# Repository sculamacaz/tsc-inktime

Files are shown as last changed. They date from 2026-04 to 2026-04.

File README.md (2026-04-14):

# InkTime

Author: Luca Mazilescu

## Block Diagram

<p align="center">
  InkTime Block Diagram
</p>

## Hardware Functionality

### Microcontroller

The system is built around a Nordic **nRF52840** SoC (Arm Cortex-M4F @ 64 MHz, 1 MB flash, 256 kB RAM). It was chosen because it integrates a 2.4 GHz radio supporting Bluetooth Low Energy alongside a USB 2.0 full-speed controller, which covers both the wireless sync path and the USB-C data path without any external transceiver. The MCU runs from a 32 MHz high-frequency crystal (XC1/XC2) for the radio and CPU, and a 32.768 kHz low-frequency crystal (XL1/XL2) for the RTC and low-power sleep timing — accurate timekeeping is the whole point of a watch, so the LFXO is not optional.

An on-board 2.4 GHz chip antenna (2450AT18B100E) is placed at the edge of the PCB with a keep-out area underneath, fed from the `ANT` pin through a matching network.

### Display — E-Paper (SPI)

A reflective e-paper display is driven over **SPI** using SCK (P0.02), MOSI (P0.03) and a dedicated chip-select (P0.05). Three auxiliary GPIOs handle the panel-specific control lines: `EPD_DC` (P0.15) switches between command and data bytes, `EPD_RST` (P0.16) resets the display controller, and `EPD_BUSY` (P0.17) is an input the MCU polls while the panel completes a refresh. The display connects through a 24-pin FPC.

Because e-paper draws current only during a refresh (and essentially zero while displaying a static image), the entire display rail is gated by a PFET whose gate is driven from P1.01. Firmware can therefore cut power to the panel completely between updates, which is the dominant reason this watch can be expected to last days on a charge rather than hours.

### IMU — BMA421 (I²C)

A Bosch **BMA421** 3-axis accelerometer sits on the shared I²C bus. It provides raw acceleration data plus on-chip step counting functionality. Two interrupt lines, `IMU_INT1` (P0.08) and `IMU_INT2` (P1.08), let the sensor wake the MCU from deep sleep when a gesture or step event occurs, so the CPU does not have to poll the bus continuously.

### Haptics — DRV2605 (I²C)

A TI **DRV2605L** haptic driver actuates a coin LRA/ERM motor for notifications and UI feedback. It is configured over I²C and can play back effects from its internal ROM library, so the MCU only issues short "play effect N" commands rather than streaming waveforms. An enable line (`HAPTIC_EN`, P0.12) lets the MCU fully power the driver down when idle.

### Power management — BQ25180 + MAX17048 + RT6160

USB-C provides 5 V in through a USBLC6-2SC6Y ESD protector, with the two required 5.1 kΩ CC pull-downs advertising the device as a sink. A **BQ25180** single-cell Li-ion charger manages the LiPo battery: it handles CC/CV charging from USB, switches between USB and battery as the system source, and reports faults over I²C and on the `PMIC_INT` line (P0.11).

The system rail is generated by an **RT6160** buck-boost regulator producing a stable `3V3` across the full battery voltage range (~3.0–4.2 V), which is important because a plain buck would drop out near end-of-discharge and a plain boost would waste efficiency when the cell is full.

State-of-charge is tracked by a **MAX17048** fuel gauge directly on the battery node. It uses Maxim's ModelGauge algorithm, so no external current-sense resistor is needed — the MCU just reads the remaining percentage and cell voltage over I²C, and an `ALERT` line (P1.10) fires on programmable under/over-voltage thresholds.

### Inputs — Buttons

Three user buttons are connected to P0.13, P0.14 and P1.02 as active-low inputs with RC debounce. They use the MCU's internal pull-ups and can trigger GPIOTE interrupts to wake the device from System OFF.

### Shared I²C bus

All four I²C peripherals (BMA421, MAX17048, DRV2605L, BQ25180) share a single bus on SDA (P0.06) and SCL (P0.07), with 3.3 kΩ pull-ups to `3V3`. The devices have distinct 7-bit addresses, so one TWI instance on the nRF52840 is sufficient. Running I²C at 400 kHz (Fast-mode) is more than enough headroom for the low-bandwidth status reads these sensors require.

### Debug

An SWD interface (`SWDCLK`, `SWDIO`, optional `SWO` on P1.00) is exposed through a Tag-Connect TC2030 footprint, which avoids placing a bulky 2×5 header on a wearable-sized PCB.

### Expected capabilities

With the hardware described above, firmware would be able to: keep accurate time from the LFXO-backed RTC, render watch faces and menus on the e-paper display, detect steps and wrist-raise via the BMA421, deliver haptic notifications, communicate with a phone over BLE, enumerate as a USB device for charging and data, and report battery percentage and charger state in real time.

## Pinout Table

| Pin | Signal | Direction | Peripheral | Description |
|-----|---|---|---|---|
| P0.02 | SPI_SCK | Output | E-Paper Display | SPI clock |
| P0.03 | SPI_MOSI | Output | E-Paper Display | SPI data out |
| P0.05 | EPD_CS | Output | E-Paper Display | Chip select |
| P0.06 | SDA | Bidir | Fuel Gauge, Charger, IMU, Haptics | Shared I2C data |
| P0.07 | SCL | Output | Fuel Gauge, Charger, IMU, Haptics | Shared I2C clock |
| P0.08 | IMU_INT1 | Input | IMU (BMA421) | Interrupt line 1 |
| P0.11 | PMIC_INT | Input | Charger (BQ25180) | Fault/status interrupt |
| P0.12 | HAPTIC_EN | Output | Haptics (DRV2605) | Driver enable |
| P0.13 | — | Input | Button 1 | User button |
| P0.14 | — | Input | Button 2 | User button |
| P0.15 | EPD_DC | Output | E-Paper Display | Data/command select |
| P0.16 | EPD_RST | Output | E-Paper Display | Display reset |
| P0.17 | EPD_BUSY | Input | E-Paper Display | Busy status |
| P0.18 | RESET | Input | — | System reset |
| P1.00 | SWO | Output | Debug (pad) | SWD trace output |
| P1.01 | — | Output | EPD power gate | EPD power control |
| P1.02 | — | Input | Button 3 | User button |
| P1.08 | IMU_INT2 | Input | IMU (BMA421) | Interrupt line 2 |
| P1.10 | ALERT | Input | Fuel Gauge (MAX17048) | UV/OV alert |
| D+ | D+ | Bidir | USB-C connector | USB data+ |
| D− | D- | Bidir | USB-C connector | USB data− |
| XL1/XL2 | — | — | 32.768 kHz crystal | Low-frequency clock |
| XC1/XC2 | — | — | 32 MHz crystal | High-frequency clock |
| SWDCLK | SWDCLK | Input | Debug (pad) | SWD clock |
| SWDIO | SWDIO | Bidir | Debug (pad) | SWD data |
| ANT | RF | Output | 2.4 GHz antenna | Wireless antenna feed |

## Bill of Materials

The full, JLCPCB validated table can be found in `Assets/JLCPCB_BOM.xlsx`. That version contains detailed information about each part, such as the associated schematic designators, descriptions, and more.

| Part Name |Qty|Link (Order + Datasheet)|
| :-- | :--: | :--: |
|BMA421|1|[Link](https://jlcpcb.com/partdetail/BoschSensortec-BMA421/C5242966)|
|0201X104K100NT|5|[Link](https://jlcpcb.com/partdetail/270391-0201X104K100NT/C284966)|
|CGA0402X5R475M250GT|1|[Link](https://jlcpcb.com/partdetail/HRE-CGA0402X5R475M250GT/C6119795)|
|KH-TYPE-C-16P|1|[Link](https://jlcpcb.com/partdetail/Shenzhen_KinghelmElec-KH_TYPE_C16P/C709357)|
|RT6160AWSC|1|[Link](https://jlcpcb.com/partdetail/RichtekTech-RT6160AWSC/C7065276)|
|SDFL1608S100KTF|1|[Link](https://jlcpcb.com/partdetail/Sunlord-SDFL1608S100KTF/C1035)|
|0201WMF220KTEE|1|[Link](https://jlcpcb.com/partdetail/479910-0201WMF220KTEE/C473517)|
|EVPAKE31A|3|[Link](https://jlcpcb.com/partdetail/PANASONIC-EVPAKE31A/C569760)|
|GRM033R61A104KE15D|5|[Link](https://jlcpcb.com/partdetail/MurataElectronics-GRM033R61A104KE15D/C76934)|
|5034802400|1|[Link](https://jlcpcb.com/partdetail/MOLEX-5034802400/C122434)|
|CM8V-T1A-32.768KHZ-9PF-20PPM-TB-QA|1|[Link](https://jlcpcb.com/partdetail/C5366546)|
|BQ25180YBGR|1|[Link](https://jlcpcb.com/partdetail/TexasInstruments-BQ25180YBGR/C3682423)|
|DRV2605YZFR|1|[Link](https://jlcpcb.com/partdetail/TexasInstruments-DRV2605YZFR/C81079)|
|2450AT18B100E|1|[Link](https://jlcpcb.com/partdetail/JohansonDielectrics-2450AT18B100E/C2917717)|
|SI1308EDL-T1-GE3|1|[Link](https://jlcpcb.com/partdetail/VishayIntertech-SI1308EDL_T1GE3/C469327)|
|GRM155R60J226ME11D|2|[Link](https://jlcpcb.com/partdetail/408393-GRM155R60J226ME11D/C415703)|
|GRM155R61H105KE05D|9|[Link](https://jlcpcb.com/partdetail/1609005-GRM155R61H105KE05D/C1518208)|
|SDCL1005C15NJTDF|1|[Link](https://jlcpcb.com/partdetail/Sunlord-SDCL1005C15NJTDF/C27143)|
|0201WMJ0000TEE|3|[Link](https://jlcpcb.com/partdetail/259867-0201WMJ0000TEE/C270337)|
|CC0201KRX5R7BB473|1|[Link](https://jlcpcb.com/partdetail/YAGEO-CC0201KRX5R7BB473/C505465)|
|CL05A475MP5NRNC|5|[Link](https://jlcpcb.com/partdetail/24469-CL05A475MP5NRNC/C23733)|
|CL05A105KA5NQNC|6|[Link](https://jlcpcb.com/partdetail/53938-CL05A105KA5NQNC/C52923)|
|SDCL1005C3N9STDF|1|[Link](https://jlcpcb.com/partdetail/Sunlord-SDCL1005C3N9STDF/C14033)|
|CR0201FH5101G|2|[Link](https://jlcpcb.com/partdetail/LIZElec-CR0201FH5101G/C100142)|
|GRM0335C1H1R0BA01D|2|[Link](https://jlcpcb.com/partdetail/MurataElectronics-GRM0335C1H1R0BA01D/C85893)|
|CL05A106MQ5NUNC|3|[Link](https://jlcpcb.com/partdetail/16204-CL05A106MQ5NUNC/C15525)|
|0201CG120J500NT|4|[Link](https://jlcpcb.com/partdetail/51400-0201CG120J500NT/C50391)|
|BQ25180YBGR|1|[Link](https://jlcpcb.com/partdetail/TexasInstruments-BQ25180YBGR/C3682423)|
|MAX17048G+T10|1|[Link](https://jlcpcb.com/partdetail/2777647-MAX17048GT10/C2682616)|
|NX2016SA-32MHZ-STD-CZS-5|1|[Link](https://jlcpcb.com/partdetail/NDK-NX2016SA_32MHZ_STD_CZS5/C843260)|
|0201WMJ0332TEE|2|[Link](https://jlcpcb.com/partdetail/259848-0201WMJ0332TEE/C270318)|
|MBR0530|3|[Link](https://jlcpcb.com/partdetail/78464-MBR0530/C77336)|
|FTC252012SR47MBCA|1|[Link](https://jlcpcb.com/partdetail/6763488-FTC252012SR47MBCA/C5832368)|
|DMG2305UX-7|1|[Link](https://jlcpcb.com/partdetail/DiodesIncorporated-DMG2305UX7/C150470)|
|USBLC6-2SC6Y|1|[Link](https://jlcpcb.com/partdetail/TECHPUBLIC-USBLC62SC6Y/C5310974)|
|UCR006YVPFLR470|1|[Link](https://jlcpcb.com/partdetail/ROHMSemicon-UCR006YVPFLR470/C2089071)|
|CPF0201D10KC1|6|[Link](https://jlcpcb.com/partdetail/TEConnectivity-CPF0201D10KC1/C4187156)|
|744043680|1|[Link](https://jlcpcb.com/partdetail/WurthElektronik-744043680/C2045671)|
|GRM0335C1H101JA01D|1|[Link](https://jlcpcb.com/partdetail/MurataElectronics-GRM0335C1H101JA01D/C76922)|
|NRF52840-QIAA-R7|1|[Link](https://jlcpcb.com/partdetail/NordicSemicon-NRF52840_QIAAR7/C1851953)|

## Renders

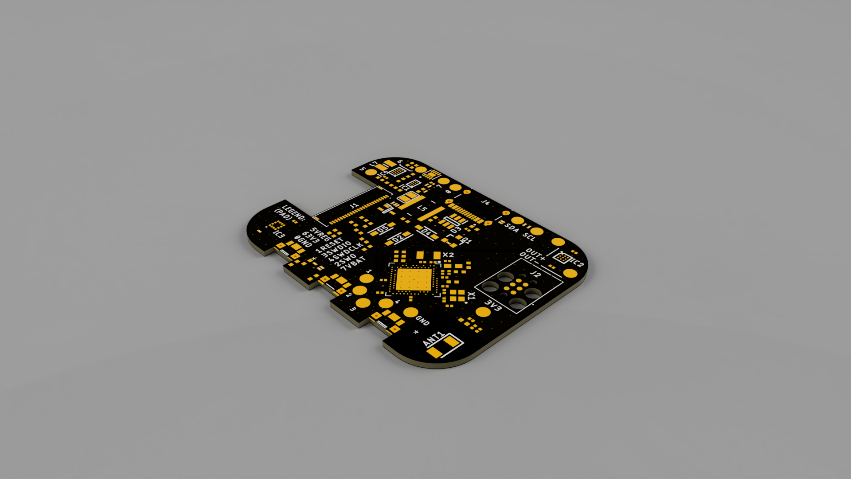
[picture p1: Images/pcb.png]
PCB

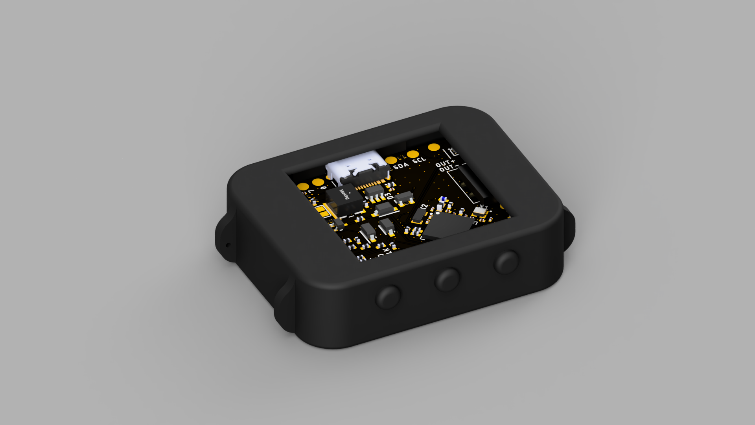
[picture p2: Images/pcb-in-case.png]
Case

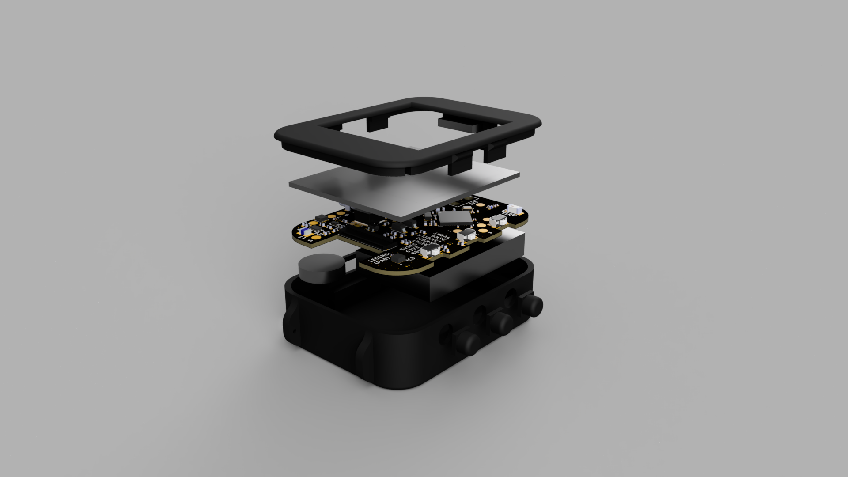
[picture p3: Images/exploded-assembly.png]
Exploded View


## Design Details

### Schematic and Components

The reference schematic was double-checked with information from each component's datasheet.
Mismatches were flagged and investigated, usually stemming from older versions of the reference circuits being used by the reference schematic.

### PCB Layout and Routing

Manufacturing parameters were kept within the ranges recommended by JLCPCB's standard rigid PCB assembly service.

A top ground pour was stitched to the ground plane, and more granular manual stitching was performed around the antenna feed line.

Teardrops were generated at most trace joints, and angles were carefully considered during routing.
Since Fusion exhibits buggy behavior when generating teardrops for off-grid rotations,
the shapes were manually smoothed for traces in close proximity to the MCU,
since it's placed at 45 degrees.

Due to space constraints and the minimum recommended text height being 1mm,
the silkscreen uses an indexed legend to allow labeling in narrow areas.
ICs, pads, and any larger components have labels on the silkscreen.

In order to achieve mechanical robustness, internal annular rings were kept large.
To accomodate, some unused pins of the MCU's package were masked, thus electrically isolating them from any traces running below.

VIA-in-pad (ViP) was liberally used for the smaller SMD multi-pin components.
DRC errors stemming from ViP-related clearance were manually approved.

Spatial constraints like the antenna's keep out zone, crystal oscillator trace length,
and IMU-shaker distance maximization were carefully considered. Decoupling capacitors were also placed in close proximity to the relevant pins.

USB (D+, D-) lines were differentially routed, keeping lengths approximately equal, and the lines close together.

### 3D Design

Detailed models of every component were retreived and integrated into the 3D PCB model.

The full closed-case assembly was checked for mechanical interference.
A potential problem was found regarding the maximum height of the battery listed in its datasheet,
as the case's bottom cavity doesn't provide enough clearance below the PCB.
This may or may not be a problem in practice, the case was left as-is to be tested in a prototype.

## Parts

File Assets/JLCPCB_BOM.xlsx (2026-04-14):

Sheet: JLCPCB BOM Tool - BOM Matching
JLCPCB BOM Tool - BOM Matching
BOM name：bom-JLCPCB Assembly Order.xlsx |  |  |  | Download Time：2026-04-15 00:02:17 |  |  |  | * Our matching results are updated in real-time, but stock and prices may change. If it's been over 24 hours, please re-match before placing your order.
PCB Assembled Qty：5 |  |  |  | Est. Total Price：143.8173 (Pre-order parts require a quotation for final pricing.)
Your BOM |  |  |  | Matched Parts |  |  |  |  |  |  | Order Information
Designator | Comment | Footprint | JLCPCB Part # | Matches | Part # | Manufacturer | Footprint | Description | Category | Warning | JLCPCB Part # | Product link | Source | Lib Type | MOQ | Availability | My Parts(JLCPCB Parts) | My Parts(Global sourcing & consigned parts) | Rec. Order Qty | Unit Price ($) | Total Price ($)
IC3 | BMA423 | LGA12 |  | Unconfirmed | BMA421 | Bosch Sensortec | LGA12 | LGA-12(2x2) Accelerometers ROHS | Accelerometers |  | C5242966 | https://jlcpcb.com/partdetail/BoschSensortec-BMA421/C5242966 | In-stock | Extended | 1 | 2037 | 0 | 0 | 5 | 0.841 | 4.205
C23,C27,C32,C34,C42 | 0.1uF | 0201 |  | Unconfirmed | 0201X104K100NT | FH (Guangdong Fenghua Advanced Tech) | 0201 | 100nF 10V X5R ±10% 0201 Multilayer Ceramic Capacitors MLCC - SMD/SMT ROHS | Multilayer Ceramic Capacitors MLCC - SMD/SMT | 1.The comment (0201X104K100NT) of this part does not match the one (0.1uF) provided in your BOM. Please confirm; | C284966 | https://jlcpcb.com/partdetail/270391-0201X104K100NT/C284966 | In-stock | Extended | 1 | 1767408 | 0 | 0 | 37 | 0.0008 | 0.0296
C2-EP-DR | 4.7uF/25V | 0402 |  | Unconfirmed | CGA0402X5R475M250GT | HRE | 0402 | 25V 4.7uF X5R ±20% 0402 Multilayer Ceramic Capacitors MLCC - SMD/SMT ROHS | Multilayer Ceramic Capacitors MLCC - SMD/SMT | 1.The comment (CGA0402X5R475M250GT) of this part does not match the one (4.7uF/25V) provided in your BOM. Please confirm; | C6119795 | https://jlcpcb.com/partdetail/HRE-CGA0402X5R475M250GT/C6119795 | In-stock | Extended | 1 | 515427 | 0 | 0 | 15 | 0.0132 | 0.198
J4 | KH-TYPE-C-16P | SMD |  | Select by System | KH-TYPE-C-16P | Shenzhen Kinghelm Elec | SMD | -40℃~+85℃ 1 10,000 cycles 16P 30V 3A 7.81mm Female Surface Mount, Right Angle Type-C SMD USB Connectors ROHS | USB Connectors |  | C709357 | https://jlcpcb.com/partdetail/Shenzhen_KinghelmElec-KH_TYPE_C16P/C709357 | In-stock | Extended | 1 | 250180 | 0 | 0 | 5 | 0.076 | 0.38
IC9 | RT6160AWSC | 15-UFBGA,WLCSP |  | Select by System | RT6160AWSC | Richtek Tech | 15-UFBGA,WLCSP | -40℃~+125℃ 1 1uA 2.025V~5.2V 2.2MHz 2.2V~5.5V 3A Adjustable Buck-Boost Buck-Boost Built-in Yes WLCSP-15B(2.3x1.4) DC-DC Converters ROHS | DC-DC Converters |  | C7065276 | https://jlcpcb.com/partdetail/RichtekTech-RT6160AWSC/C7065276 | In-stock | Extended | 1 | 5993 | 0 | 0 | 5 | 0.5868 | 2.934
L2 | 10uH | 0603 |  | Unconfirmed | SDFL1608S100KTF | Sunlord | 0603 | 1.85Ω 10uH 17MHz 30@2MHz 3mA ±10% 0603 Inductors (SMD) ROHS | Inductors (SMD) | 1.The comment (SDFL1608S100KTF) of this part does not match the one (10uH) provided in your BOM. Please confirm; | C1035 | https://jlcpcb.com/partdetail/Sunlord-SDFL1608S100KTF/C1035 | In-stock | Basic | 1 | 314612 | 0 | 0 | 20 | 0.0175 | 0.35
R_TYPE_SEL | 2.2Ω | 0201 |  | Select by System | 0201WMF220KTEE | UNI-ROYAL(Uniroyal Elec) | 0201 | -100ppm/℃~+350ppm/℃ -55℃~+155℃ 2.2Ω 25V 50mW Thick Film Resistor ±1% 0201 Chip Resistor - Surface Mount ROHS | Chip Resistor - Surface Mount |  | C473517 | https://jlcpcb.com/partdetail/479910-0201WMF220KTEE/C473517 | In-stock | Extended | 1 | 489132 | 0 | 0 | 20 | 0.0012 | 0.024
SW_DN,SW_ENT,SW_UP | EVPAKE31A | SMD,3.9x2.9mm |  | Unconfirmed | EVPAKE31A | PANASONIC | SMD,3.9x2.9mm | -40℃~+85℃ 1.6N 1.6mm 15V 2.9mm 20mA 3.9mm 500,000 Cycles IP67 J-Lead Rectangular Button SPST Surface Mount,Vertical White With Bracket SMD,3.9x2.9mm Tactile Switches ROHS | Tactile Switches | 1.There may be multiple types of parts, but one type of part has been matched. Please check.; | C569760 | https://jlcpcb.com/partdetail/PANASONIC-EVPAKE31A/C569760 | In-stock | Extended | 1 | 26113 | 0 | 0 | 17 | 0.1596 | 2.7132
C5,C7,C8,C12,C19 | 100nF | 0201 |  | Unconfirmed | GRM033R61A104KE15D | Murata Electronics | 0201 | 100nF 10V X5R ±10% 0201 Multilayer Ceramic Capacitors MLCC - SMD/SMT ROHS | Multilayer Ceramic Capacitors MLCC - SMD/SMT | 1.The comment (GRM033R61A104KE15D) of this part does not match the one (100nF) provided in your BOM. Please confirm; | C76934 | https://jlcpcb.com/partdetail/MurataElectronics-GRM033R61A104KE15D/C76934 | In-stock | Extended | 1 | 1241377 | 0 | 0 | 37 | 0.002 | 0.074
J1 | 5034802400 | SMD,P=0.5mm, right angle |  | Select by System | 5034802400 | MOLEX | SMD,P=0.5mm, right angle | -40℃~+105℃ 0.3mm 0.5mm 1mm 24P 500mA 50V Double-Sided Contacts, Top and Bottom Entry Gold Hinged Lid Phosphor bronze Surface Mount, Right Angle SMD,P=0.5mm,Surface Mount，Right Angle FFC, FPC (Flat Flexible) Connector Assemblies ROHS | FFC, FPC (Flat Flexible) Connector Assemblies |  | C122434 | https://jlcpcb.com/partdetail/MOLEX-5034802400/C122434 | In-stock | Extended | 1 | 21 | 0 | 0 | 5 | 0.849 | 4.245
X2 | 32.768kHz | SMD,3.2x1.5mm |  | Select by System | CM8V-T1A-32.768KHZ-9PF-20PPM-TB-QA | Micro Crystal | SMD,3.2x1.5mm | -40℃~+125℃ 32.768kHz 70kΩ 9pF ±20ppm SMD2012-2P Crystals ROHS | Crystals |  | C5366546 | https://jlcpcb.com/partdetail/C5366546 | In-stock | Extended | 1 | 2791 | 0 | 0 | 5 | 0.6203 | 3.1015
EPD_C5 | 0.1uF/50V | 0402 |  | Unconfirmed | BQ25180YBGR | Texas Instruments | 0402 | -40℃~+125℃ 1 1A 3.2uA 4.65V 5.5V Charging IC I2C Lithium Battery、LiFePO4 Battery Support 恒流充电、恒压充电、涓流充电、自动再充电、充电终止、可编程充电电流、过放保护、Overcurrent Protection、Short-Circuit Protection、过压保护 DSBGA-8(1.1x1.6) Battery Management ROHS | Battery Management | 1.The footprint (DSBGA-8(1.1x1.6)) of this part does not match the one (0402) provided in your BOM. Please confirm; 2.Multiple lines in the BOM have been matched to the same part. Please check if the matching is correct. ; | C3682423 | https://jlcpcb.com/partdetail/TexasInstruments-BQ25180YBGR/C3682423 | In-stock | Extended | 1 | 969 | 0 | 0 | 10 | 1.7954 | 17.954
IC2 | DRV2605YZFR | BGA9 |  | Select by System | DRV2605YZFR | Texas Instruments | BGA9 | -40℃~+85℃ 2.5V~5.5V I2C DSBGA-9 Brushed DC Motor Drivers ROHS | Brushed DC Motor Drivers |  | C81079 | https://jlcpcb.com/partdetail/TexasInstruments-DRV2605YZFR/C81079 | In-stock | Extended | 1 | 334 | 0 | 0 | 5 | 1.3286 | 6.643
ANT1 | 2450AT18B100E | 1206 |  | Select by System | 2450AT18B100E | Johanson Dielectrics | 1206 | -45℃~+125℃ 0.5dBi 1.3mm 1.6mm 100MHz 2.45GHz 2W 3.2mm 50Ω Patch Antenna 1206 Antennas ROHS | Antennas |  | C2917717 | https://jlcpcb.com/partdetail/JohansonDielectrics-2450AT18B100E/C2917717 | In-stock | Extended | 1 | 317 | 0 | 0 | 5 | 1.0408 | 5.204
Q3 | SI1308EDL-T1-GE3 | SOT-323 |  | Select by System | SI1308EDL-T1-GE3 | Vishay Intertech | SOT-323 | -55℃~+150℃ 1 N-channel 1.4nC@10V 1.5A 1.5V 105pF 11pF 132mΩ@10V 23pF 30V 400mW N-Channel SOT-323 MOSFETs ROHS | MOSFETs |  | C469327 | https://jlcpcb.com/partdetail/VishayIntertech-SI1308EDL_T1GE3/C469327 | In-stock | Extended | 1 | 16217 | 0 | 0 | 7 | 0.1853 | 1.2971
C25,C33 | 22uF | 0402 |  | Unconfirmed | GRM155R60J226ME11D | Murata Electronics | 0402 | 22uF 6.3V X5R ±20% 0402 Multilayer Ceramic Capacitors MLCC - SMD/SMT ROHS | Multilayer Ceramic Capacitors MLCC - SMD/SMT | 1.The comment (GRM155R60J226ME11D) of this part does not match the one (22uF) provided in your BOM. Please confirm; | C415703 | https://jlcpcb.com/partdetail/408393-GRM155R60J226ME11D/C415703 | In-stock | Extended | 1 | 282949 | 0 | 0 | 14 | 0.0435 | 0.609
EPD_C1,EPD_C2,EPD_C6,EPD_C7,EPD_C8,EPD_C9,EPD_C10,EPD_C11,EPD_C12 | 1uF/50V | 0402 |  | Select by System | GRM155R61H105KE05D | Murata Electronics | 0402 | 1uF 50V X5R ±10% 0402 Multilayer Ceramic Capacitors MLCC - SMD/SMT ROHS | Multilayer Ceramic Capacitors MLCC - SMD/SMT |  | C1518208 | https://jlcpcb.com/partdetail/1609005-GRM155R61H105KE05D/C1518208 | In-stock | Extended | 1 | 264318 | 0 | 0 | 49 | 0.0304 | 1.4896
L3 | 15nH | 0402 |  | Unconfirmed | SDCL1005C15NJTDF | Sunlord | 0402 | 15nH 2.3GHz 300mA 500mΩ 8@100MHz ±5% 0402 Inductors (SMD) ROHS | Inductors (SMD) | 1.The comment (SDCL1005C15NJTDF) of this part does not match the one (15nH) provided in your BOM. Please confirm; | C27143 | https://jlcpcb.com/partdetail/Sunlord-SDCL1005C15NJTDF/C27143 | In-stock | Extended | 1 | 481616 | 0 | 0 | 20 | 0.0053 | 0.106
R2,R3,R4 | 0Ω | 0201 |  | Select by System | 0201WMJ0000TEE | UNI-ROYAL(Uniroyal Elec) | 0201 | -55℃~+155℃ 0Ω 25V 50mW Thick Film Resistor ±5% 0201 Chip Resistor - Surface Mount ROHS | Chip Resistor - Surface Mount |  | C270337 | https://jlcpcb.com/partdetail/259867-0201WMJ0000TEE/C270337 | In-stock | Extended | 1 | 908769 | 0 | 0 | 25 | 0.0008 | 0.02
C16 | 47nF | 0201 |  | Unconfirmed | CC0201KRX5R7BB473 | YAGEO | 0201 | 16V 47nF X5R ±10% 0201 Multilayer Ceramic Capacitors MLCC - SMD/SMT ROHS | Multilayer Ceramic Capacitors MLCC - SMD/SMT | 1.The comment (CC0201KRX5R7BB473) of this part does not match the one (47nF) provided in your BOM. Please confirm; | C505465 | https://jlcpcb.com/partdetail/YAGEO-CC0201KRX5R7BB473/C505465 | In-stock | Extended | 1 | 59476 | 0 | 0 | 20 | 0.0031 | 0.062
C6,C14,C20,C21,C43 | 4.7uF | 0402 |  | Unconfirmed | CL05A475MP5NRNC | Samsung Electro-Mechanics | 0402 | 10V 4.7uF X5R ±20% 0402 Multilayer Ceramic Capacitors MLCC - SMD/SMT ROHS | Multilayer Ceramic Capacitors MLCC - SMD/SMT | 1.The comment (CL05A475MP5NRNC) of this part does not match the one (4.7uF) provided in your BOM. Please confirm; | C23733 | https://jlcpcb.com/partdetail/24469-CL05A475MP5NRNC/C23733 | In-stock | Basic | 1 | 3874505 | 0 | 0 | 35 | 0.0059 | 0.2065
C15,C29,C30,C31,C37,C38 | 1uF | 0402 |  | Unconfirmed | CL05A105KA5NQNC | Samsung Electro-Mechanics | 0402 | 1uF 25V X5R ±10% 0402 Multilayer Ceramic Capacitors MLCC - SMD/SMT ROHS | Multilayer Ceramic Capacitors MLCC - SMD/SMT | 1.The comment (CL05A105KA5NQNC) of this part does not match the one (1uF) provided in your BOM. Please confirm; | C52923 | https://jlcpcb.com/partdetail/53938-CL05A105KA5NQNC/C52923 | In-stock | Basic | 1 | 11272053 | 0 | 0 | 40 | 0.0041 | 0.164
L1 | 3.9nH | 0402 |  | Unconfirmed | SDCL1005C3N9STDF | Sunlord | 0402 | 200mΩ 3.9nH 300mA 4GHz 8@100MHz Multilayer inductor 0402 Inductors (SMD) ROHS | Inductors (SMD) | 1.The comment (SDCL1005C3N9STDF) of this part does not match the one (3.9nH) provided in your BOM. Please confirm; | C14033 | https://jlcpcb.com/partdetail/Sunlord-SDCL1005C3N9STDF/C14033 | In-stock | Extended | 1 | 151853 | 0 | 0 | 20 | 0.0053 | 0.106
R1_USB,R2_USB | 5.1kΩ | 0201 |  | Select by System | CR0201FH5101G | LIZ Elec | 0201 | -55℃~+125℃ 25V 5.1kΩ 50mW Thick Film Resistor ±1% ±250ppm/℃ 0201 Chip Resistor - Surface Mount ROHS | Chip Resistor - Surface Mount |  | C100142 | https://jlcpcb.com/partdetail/LIZElec-CR0201FH5101G/C100142 | In-stock | Extended | 1 | 7185 | 0 | 0 | 20 | 0.0011 | 0.022
C3,C4 | 1pF | 0201 |  | Unconfirmed | GRM0335C1H1R0BA01D | Murata Electronics | 0201 | 1pF 50V C0G 0201 Multilayer Ceramic Capacitors MLCC - SMD/SMT ROHS | Multilayer Ceramic Capacitors MLCC - SMD/SMT | 1.The comment (GRM0335C1H1R0BA01D) of this part does not match the one (1pF) provided in your BOM. Please confirm; | C85893 | https://jlcpcb.com/partdetail/MurataElectronics-GRM0335C1H1R0BA01D/C85893 | In-stock | Extended | 1 | 94915 | 0 | 0 | 20 | 0.0031 | 0.062
C1-EP-DR,C24,C39 | 10uF | 0402 |  | Unconfirmed | CL05A106MQ5NUNC | Samsung Electro-Mechanics | 0402 | 10uF 6.3V X5R ±20% 0402 Multilayer Ceramic Capacitors MLCC - SMD/SMT ROHS | Multilayer Ceramic Capacitors MLCC - SMD/SMT | 1.The comment (CL05A106MQ5NUNC) of this part does not match the one (10uF) provided in your BOM. Please confirm; 2.There may be multiple types of parts, but one type of part has been matched. Please check.; | C15525 | https://jlcpcb.com/partdetail/16204-CL05A106MQ5NUNC/C15525 | In-stock | Basic | 1 | 9525242 | 0 | 0 | 25 | 0.0065 | 0.1625
C1,C2,C17,C18 | 12pF | 0201 |  | Unconfirmed | 0201CG120J500NT | FH (Guangdong Fenghua Advanced Tech) | 0201 | 12pF 50V C0G ±5% 0201 Multilayer Ceramic Capacitors MLCC - SMD/SMT ROHS | Multilayer Ceramic Capacitors MLCC - SMD/SMT | 1.The comment (0201CG120J500NT) of this part does not match the one (12pF) provided in your BOM. Please confirm; | C50391 | https://jlcpcb.com/partdetail/51400-0201CG120J500NT/C50391 | In-stock | Extended | 1 | 96412 | 0 | 0 | 30 | 0.0008 | 0.024
IC1 | BQ25180YBGR | BGA8 |  | Unconfirmed | BQ25180YBGR | Texas Instruments | BGA8 | -40℃~+125℃ 1 1A 3.2uA 4.65V 5.5V Charging IC I2C Lithium Battery、LiFePO4 Battery Support 恒流充电、恒压充电、涓流充电、自动再充电、充电终止、可编程充电电流、过放保护、Overcurrent Protection、Short-Circuit Protection、过压保护 DSBGA-8(1.1x1.6) Battery Management ROHS | Battery Management | 1.Multiple lines in the BOM have been matched to the same part. Please check if the matching is correct. ; | C3682423 | https://jlcpcb.com/partdetail/TexasInstruments-BQ25180YBGR/C3682423 | In-stock | Extended | 1 | 969 | 0 | 0 | 10 | 1.7954 | 17.954
U3 | MAX17048G+T10 | DFN-8-EP |  | Select by System | MAX17048G+T10 | Analog Devices Inc./Maxim Integrated | DFN-8-EP | -40℃~+85℃ 1 2.5V~4.5V 3uA I2C Lithium Battery Not supported Not supported DFN-8-EP(2x2) Battery Management ROHS | Battery Management |  | C2682616 | https://jlcpcb.com/partdetail/2777647-MAX17048GT10/C2682616 | In-stock | Extended | 1 | 10503 | 0 | 0 | 5 | 2.235 | 11.175
X1 | 32MHz | 4-SMD,2x1.6mm |  | Select by System | NX2016SA-32MHZ-STD-CZS-5 | NDK | 4-SMD,2x1.6mm | Crystal Oscillator SMD2016-4P Crystals ROHS | Crystals |  | C843260 | https://jlcpcb.com/partdetail/NDK-NX2016SA_32MHZ_STD_CZS5/C843260 | In-stock | Extended | 1 | 2780 | 0 | 0 | 5 | 0.2782 | 1.391
R17,R18 | 3.3kΩ | 0201 |  | Select by System | 0201WMJ0332TEE | UNI-ROYAL(Uniroyal Elec) | 0201 | -55℃~+155℃ 25V 3.3kΩ 50mW Thick Film Resistor ±200ppm/℃ ±5% 0201 Chip Resistor - Surface Mount ROHS | Chip Resistor - Surface Mount |  | C270318 | https://jlcpcb.com/partdetail/259848-0201WMJ0332TEE/C270318 | In-stock | Extended | 1 | 12985 | 0 | 0 | 20 | 0.0007 | 0.014
D2,D4,D5 | MBR0530 | SOD-123 |  | Select by System | MBR0530 | Jiangsu Changjing Electronics Technology Co., Ltd. | SOD-123 | 1 Independent 30V 5.5A 500mA 550mV@500mA 80uA@30V SOD-123 Schottky Diodes ROHS | Schottky Diodes |  | C77336 | https://jlcpcb.com/partdetail/78464-MBR0530/C77336 | In-stock | Extended | 1 | 89551 | 0 | 0 | 19 | 0.0351 | 0.6669
L7 | 0.47uH/6.5A/13mΩ | SMD,2x2.5mm |  | Select by System | FTC252012SR47MBCA | cjiang (Changjiang Microelectronics Tech) | SMD,2x2.5mm | 13mΩ 470nH 6.5A 7.5A ±20% 1008 Power Inductors ROHS | Power Inductors |  | C5832368 | https://jlcpcb.com/partdetail/6763488-FTC252012SR47MBCA/C5832368 | In-stock | Extended | 1 | 155998 | 0 | 0 | 9 | 0.0408 | 0.3672
Q1 | 20V/4.2A/52mΩ/1.4W | SOT23-3 |  | Select by System | DMG2305UX-7 | Diodes Incorporated | SOT23-3 | -55℃~+150℃ 1 P-Channel 1.4W 10.2nC@4.5V 20V 52mΩ@4.5V、100mΩ@2.5V 5A 77pF 808pF 85pF 900mV P-Channel SOT-23 MOSFETs ROHS | MOSFETs |  | C150470 | https://jlcpcb.com/partdetail/DiodesIncorporated-DMG2305UX7/C150470 | In-stock | Extended | 1 | 40635 | 0 | 0 | 9 | 0.1366 | 1.2294
D3 | USBLC6-2SC6Y | SOT23-6 |  | Select by System | USBLC6-2SC6Y | TECH PUBLIC | SOT23-6 | -55℃~+125℃ 0.6pF、1pF 12V 150W@8/20us 5V 6.5V 80nA 9A@8/20us IEC 61000-4-2、IEC 61000-4-5、IEC 61000-4-4 SOT-23-6 ESD and Surge Protection (TVS/ESD) ROHS | ESD and Surge Protection (TVS/ESD) |  | C5310974 | https://jlcpcb.com/partdetail/TECHPUBLIC-USBLC62SC6Y/C5310974 | In-stock | Extended | 1 | 4299 | 0 | 0 | 7 | 0.1801 | 1.2607
R1_EP_DR | 0.47Ω | 0201 |  | Select by Customer | UCR006YVPFLR470 | ROHM Semicon | 0201 | 0ppm/℃~+300ppm/℃ 100mW 470mΩ SMD Shunt ±1% 0201 Current Sense Resistors / Shunt Resistors ROHS | Current Sense Resistors / Shunt Resistors | 1.The comment (UCR006YVPFLR470) of this part does not match the one (0.47Ω) provided in your BOM. Please confirm; | C2089071 | https://jlcpcb.com/partdetail/ROHMSemicon-UCR006YVPFLR470/C2089071 | Pre-order | Extended | 53 | 0 | 0 | 0 | 53 | 0.1696 | 8.9888
R2_EP_DR,R5,R7,R8,R9,R_PWR_EPD | 10kΩ | 0201 |  | Unconfirmed | CPF0201D10KC1 | TE Connectivity | 0201 | -55℃~+155℃ 10kΩ 30mW Thin Film Resistor ±0.5% ±50ppm/℃ 0201 Chip Resistor - Surface Mount ROHS | Chip Resistor - Surface Mount | 1.There may be multiple types of parts, but one type of part has been matched. Please check.; | C4187156 | https://jlcpcb.com/partdetail/TEConnectivity-CPF0201D10KC1/C4187156 | Pre-order | Extended | 54 | 25 | 0 | 0 | 54 | 0.1672 | 9.0288
L5 | 744043680 | SMD,4.8x4.8mm |  | Select by System | 744043680 | Wurth Elektronik | SMD,4.8x4.8mm | 400mA 400mΩ 68uH ±30% SMD,4.8x4.8mm Power Inductors ROHS | Power Inductors |  | C2045671 | https://jlcpcb.com/partdetail/WurthElektronik-744043680/C2045671 | Pre-order | Extended | 12 | 0 | 0 | 0 | 12 | 0.8042 | 9.6504
C11 | 100pF | 0201 |  | Unconfirmed | GRM0335C1H101JA01D | Murata Electronics | 0201 | 100pF 50V C0G ±5% 0201 Multilayer Ceramic Capacitors MLCC - SMD/SMT ROHS | Multilayer Ceramic Capacitors MLCC - SMD/SMT | 1.The comment (GRM0335C1H101JA01D) of this part does not match the one (100pF) provided in your BOM. Please confirm; | C76922 | https://jlcpcb.com/partdetail/MurataElectronics-GRM0335C1H101JA01D/C76922 | Pre-order | Extended | 7408 | 2605 | 0 | 0 | 7408 | 0.0012 | 8.8896
U1 | NRF52840-QIAA-R7 | 73-VFQFN |  | Select by System | NRF52840-QIAA-R7 | Nordic Semicon | 73-VFQFN | -95dBm 1.7V~5.5V 2.4GHz 2.4GHz~2.4835GHz 2Mbps 4.82mA 6.26mA 8dBm SPI、USB、UART、I2S、PDM、PWM ZigBee、Bluetooth transceiver AQFN-73-EP(7x7) RF Transceiver ICs ROHS | RF Transceiver ICs |  | C1851953 | https://jlcpcb.com/partdetail/NordicSemicon-NRF52840_QIAAR7/C1851953 | Pre-order | Extended | 3 | 14 | 0 | 0 | 5 | 4.1631 | 20.8155

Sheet: Sheet 1
Table 1
Part Name | Qty | Slop | Link (Order + Datasheet)
BMA421 | 1 | IC3 | https://jlcpcb.com/partdetail/BoschSensortec-BMA421/C5242966
0201X104K100NT | 5 | C23,C27,C32,C34,C42 | https://jlcpcb.com/partdetail/270391-0201X104K100NT/C284966
CGA0402X5R475M250GT | 1 | C2-EP-DR | https://jlcpcb.com/partdetail/HRE-CGA0402X5R475M250GT/C6119795
KH-TYPE-C-16P | 1 | J4 | https://jlcpcb.com/partdetail/Shenzhen_KinghelmElec-KH_TYPE_C16P/C709357
RT6160AWSC | 1 | IC9 | https://jlcpcb.com/partdetail/RichtekTech-RT6160AWSC/C7065276
SDFL1608S100KTF | 1 | L2 | https://jlcpcb.com/partdetail/Sunlord-SDFL1608S100KTF/C1035
0201WMF220KTEE | 1 | R_TYPE_SEL | https://jlcpcb.com/partdetail/479910-0201WMF220KTEE/C473517
EVPAKE31A | 3 | SW_DN,SW_ENT,SW_UP | https://jlcpcb.com/partdetail/PANASONIC-EVPAKE31A/C569760
GRM033R61A104KE15D | 5 | C5,C7,C8,C12,C19 | https://jlcpcb.com/partdetail/MurataElectronics-GRM033R61A104KE15D/C76934
5034802400 | 1 | J1 | https://jlcpcb.com/partdetail/MOLEX-5034802400/C122434
CM8V-T1A-32.768KHZ-9PF-20PPM-TB-QA | 1 | X2 | https://jlcpcb.com/partdetail/C5366546
BQ25180YBGR | 1 | EPD_C5 | https://jlcpcb.com/partdetail/TexasInstruments-BQ25180YBGR/C3682423
DRV2605YZFR | 1 | IC2 | https://jlcpcb.com/partdetail/TexasInstruments-DRV2605YZFR/C81079
2450AT18B100E | 1 | ANT1 | https://jlcpcb.com/partdetail/JohansonDielectrics-2450AT18B100E/C2917717
SI1308EDL-T1-GE3 | 1 | Q3 | https://jlcpcb.com/partdetail/VishayIntertech-SI1308EDL_T1GE3/C469327
GRM155R60J226ME11D | 2 | C25,C33 | https://jlcpcb.com/partdetail/408393-GRM155R60J226ME11D/C415703
GRM155R61H105KE05D | 9 | EPD_C1,EPD_C2,EPD_C6,EPD_C7,EPD_C8,EPD_C9,EPD_C10,EPD_C11,EPD_C12 | https://jlcpcb.com/partdetail/1609005-GRM155R61H105KE05D/C1518208
SDCL1005C15NJTDF | 1 | L3 | https://jlcpcb.com/partdetail/Sunlord-SDCL1005C15NJTDF/C27143
0201WMJ0000TEE | 3 | R2,R3,R4 | https://jlcpcb.com/partdetail/259867-0201WMJ0000TEE/C270337
CC0201KRX5R7BB473 | 1 | C16 | https://jlcpcb.com/partdetail/YAGEO-CC0201KRX5R7BB473/C505465
CL05A475MP5NRNC | 5 | C6,C14,C20,C21,C43 | https://jlcpcb.com/partdetail/24469-CL05A475MP5NRNC/C23733
CL05A105KA5NQNC | 6 | C15,C29,C30,C31,C37,C38 | https://jlcpcb.com/partdetail/53938-CL05A105KA5NQNC/C52923
SDCL1005C3N9STDF | 1 | L1 | https://jlcpcb.com/partdetail/Sunlord-SDCL1005C3N9STDF/C14033
CR0201FH5101G | 2 | R1_USB,R2_USB | https://jlcpcb.com/partdetail/LIZElec-CR0201FH5101G/C100142
GRM0335C1H1R0BA01D | 2 | C3,C4 | https://jlcpcb.com/partdetail/MurataElectronics-GRM0335C1H1R0BA01D/C85893
CL05A106MQ5NUNC | 3 | C1-EP-DR,C24,C39 | https://jlcpcb.com/partdetail/16204-CL05A106MQ5NUNC/C15525
0201CG120J500NT | 4 | C1,C2,C17,C18 | https://jlcpcb.com/partdetail/51400-0201CG120J500NT/C50391
BQ25180YBGR | 1 | IC1 | https://jlcpcb.com/partdetail/TexasInstruments-BQ25180YBGR/C3682423
MAX17048G+T10 | 1 | U3 | https://jlcpcb.com/partdetail/2777647-MAX17048GT10/C2682616
NX2016SA-32MHZ-STD-CZS-5 | 1 | X1 | https://jlcpcb.com/partdetail/NDK-NX2016SA_32MHZ_STD_CZS5/C843260
0201WMJ0332TEE | 2 | R17,R18 | https://jlcpcb.com/partdetail/259848-0201WMJ0332TEE/C270318
MBR0530 | 3 | D2,D4,D5 | https://jlcpcb.com/partdetail/78464-MBR0530/C77336
FTC252012SR47MBCA | 1 | L7 | https://jlcpcb.com/partdetail/6763488-FTC252012SR47MBCA/C5832368
DMG2305UX-7 | 1 | Q1 | https://jlcpcb.com/partdetail/DiodesIncorporated-DMG2305UX7/C150470
USBLC6-2SC6Y | 1 | D3 | https://jlcpcb.com/partdetail/TECHPUBLIC-USBLC62SC6Y/C5310974
UCR006YVPFLR470 | 1 | R1_EP_DR | https://jlcpcb.com/partdetail/ROHMSemicon-UCR006YVPFLR470/C2089071
CPF0201D10KC1 | 6 | R2_EP_DR,R5,R7,R8,R9,R_PWR_EPD | https://jlcpcb.com/partdetail/TEConnectivity-CPF0201D10KC1/C4187156
744043680 | 1 | L5 | https://jlcpcb.com/partdetail/WurthElektronik-744043680/C2045671
GRM0335C1H101JA01D | 1 | C11 | https://jlcpcb.com/partdetail/MurataElectronics-GRM0335C1H101JA01D/C76922
NRF52840-QIAA-R7 | 1 | U1 | https://jlcpcb.com/partdetail/NordicSemicon-NRF52840_QIAAR7/C1851953

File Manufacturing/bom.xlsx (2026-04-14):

Comment | Designator | Footprint | JLCPCB Part #
0Ω | R2, R3, R4 | 0201 | C270337
0.1uF | C23, C27, C32, C34, C42 | 0201
0.1uF/50V | EPD_C5 | 0402 | C3682423
470mΩ | R1_EP_DR | 0201 | C2089071
0.47uH/6.5A/13mΩ | L7 | SMD,2x2.5mm | C5832368
100nF | C5, C7, C8, C12, C19 | 0201
100pF | C11 | 0201
10kΩ | R2_EP_DR, R5, R7, R8, R9, R_PWR_EPD | 0201 | C4187156
10uF | C1-EP-DR, C24, C39 | 0402
10uH | L2 | 0603
12pF | C1, C2, C17, C18 | 0201
15nH | L3 | 0402
1pF | C3, C4 | 0201
1uF | C15, C29, C30, C31, C37, C38 | 0402
1uF/50V | EPD_C1, EPD_C2, EPD_C6, EPD_C7, EPD_C8, EPD_C9, EPD_C10, EPD_C11, EPD_C12 | 0402 | C1518208
2.2Ω | R_TYPE_SEL | 0201 | C473517
20V/4.2A/52mΩ/1.4W | Q1 | SOT23-3 | C150470
22uF | C25, C33 | 0402
3.9nH | L1 | 0402
32.768kHz | X2 | SMD,3.2x1.5mm
32MHz | X1 | 4-SMD,2x1.6mm
3.3kΩ | R17, R18 | 0201 | C270318
4.7uF | C6, C14, C20, C21, C43 | 0402
4.7uF/25V | C2-EP-DR | 0402
47nF | C16 | 0201
5.1kΩ | R1_USB, R2_USB | 0201 | C100142
744043680 | L5 | SMD,4.8x4.8mm
EVPAKE31A | SW_DN, SW_ENT, SW_UP | SMD,3.9x2.9mm
2450AT18B100E | ANT1 | 1206
5034802400 | J1 | SMD,P=0.5mm, right angle
BMA421 | IC3 | LGA12
BQ25180YBGR | IC1 | BGA8
DRV2605YZFR | IC2 | BGA9
KH-TYPE-C-16P | J4 | SMD
MAX17048G+T10 | U3 | DFN-8-EP
MBR0530 | D2, D4, D5 | SOD-123
NRF52840-QIAA-R7 | U1 | 73-VFQFN
RT6160AWSC | IC9 | 15-UFBGA,WLCSP
SI1308EDL-T1-GE3 | Q3 | SOT-323
USBLC6-2SC6Y | D3 | SOT23-6

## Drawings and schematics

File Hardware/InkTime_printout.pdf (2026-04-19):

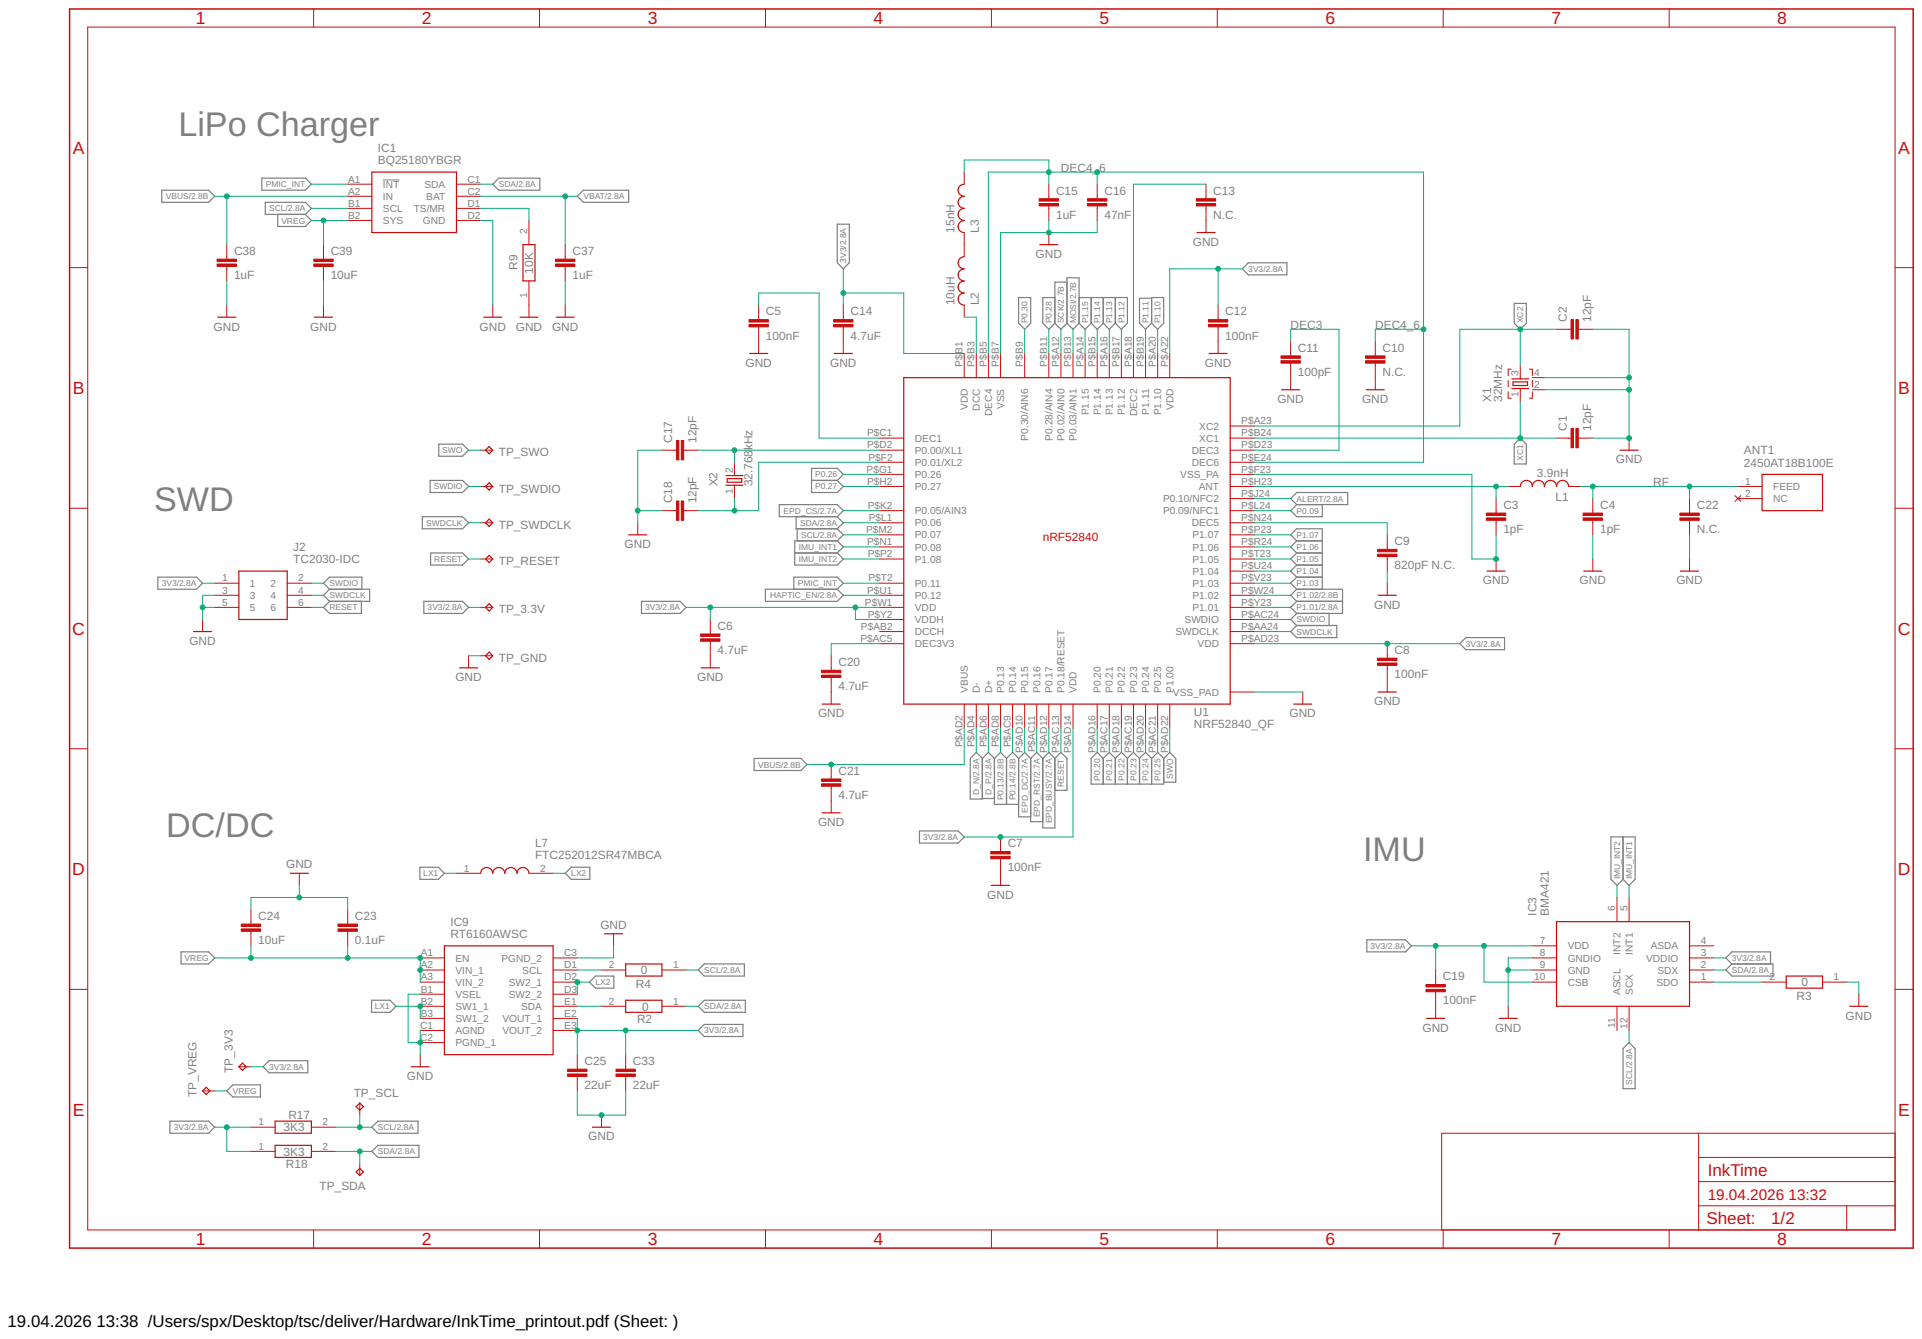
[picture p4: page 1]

19.04.2026 13:38 /Users/spx/Desktop/tsc/deliver/Hardware/InkTime_printout.pdf (Sheet: )

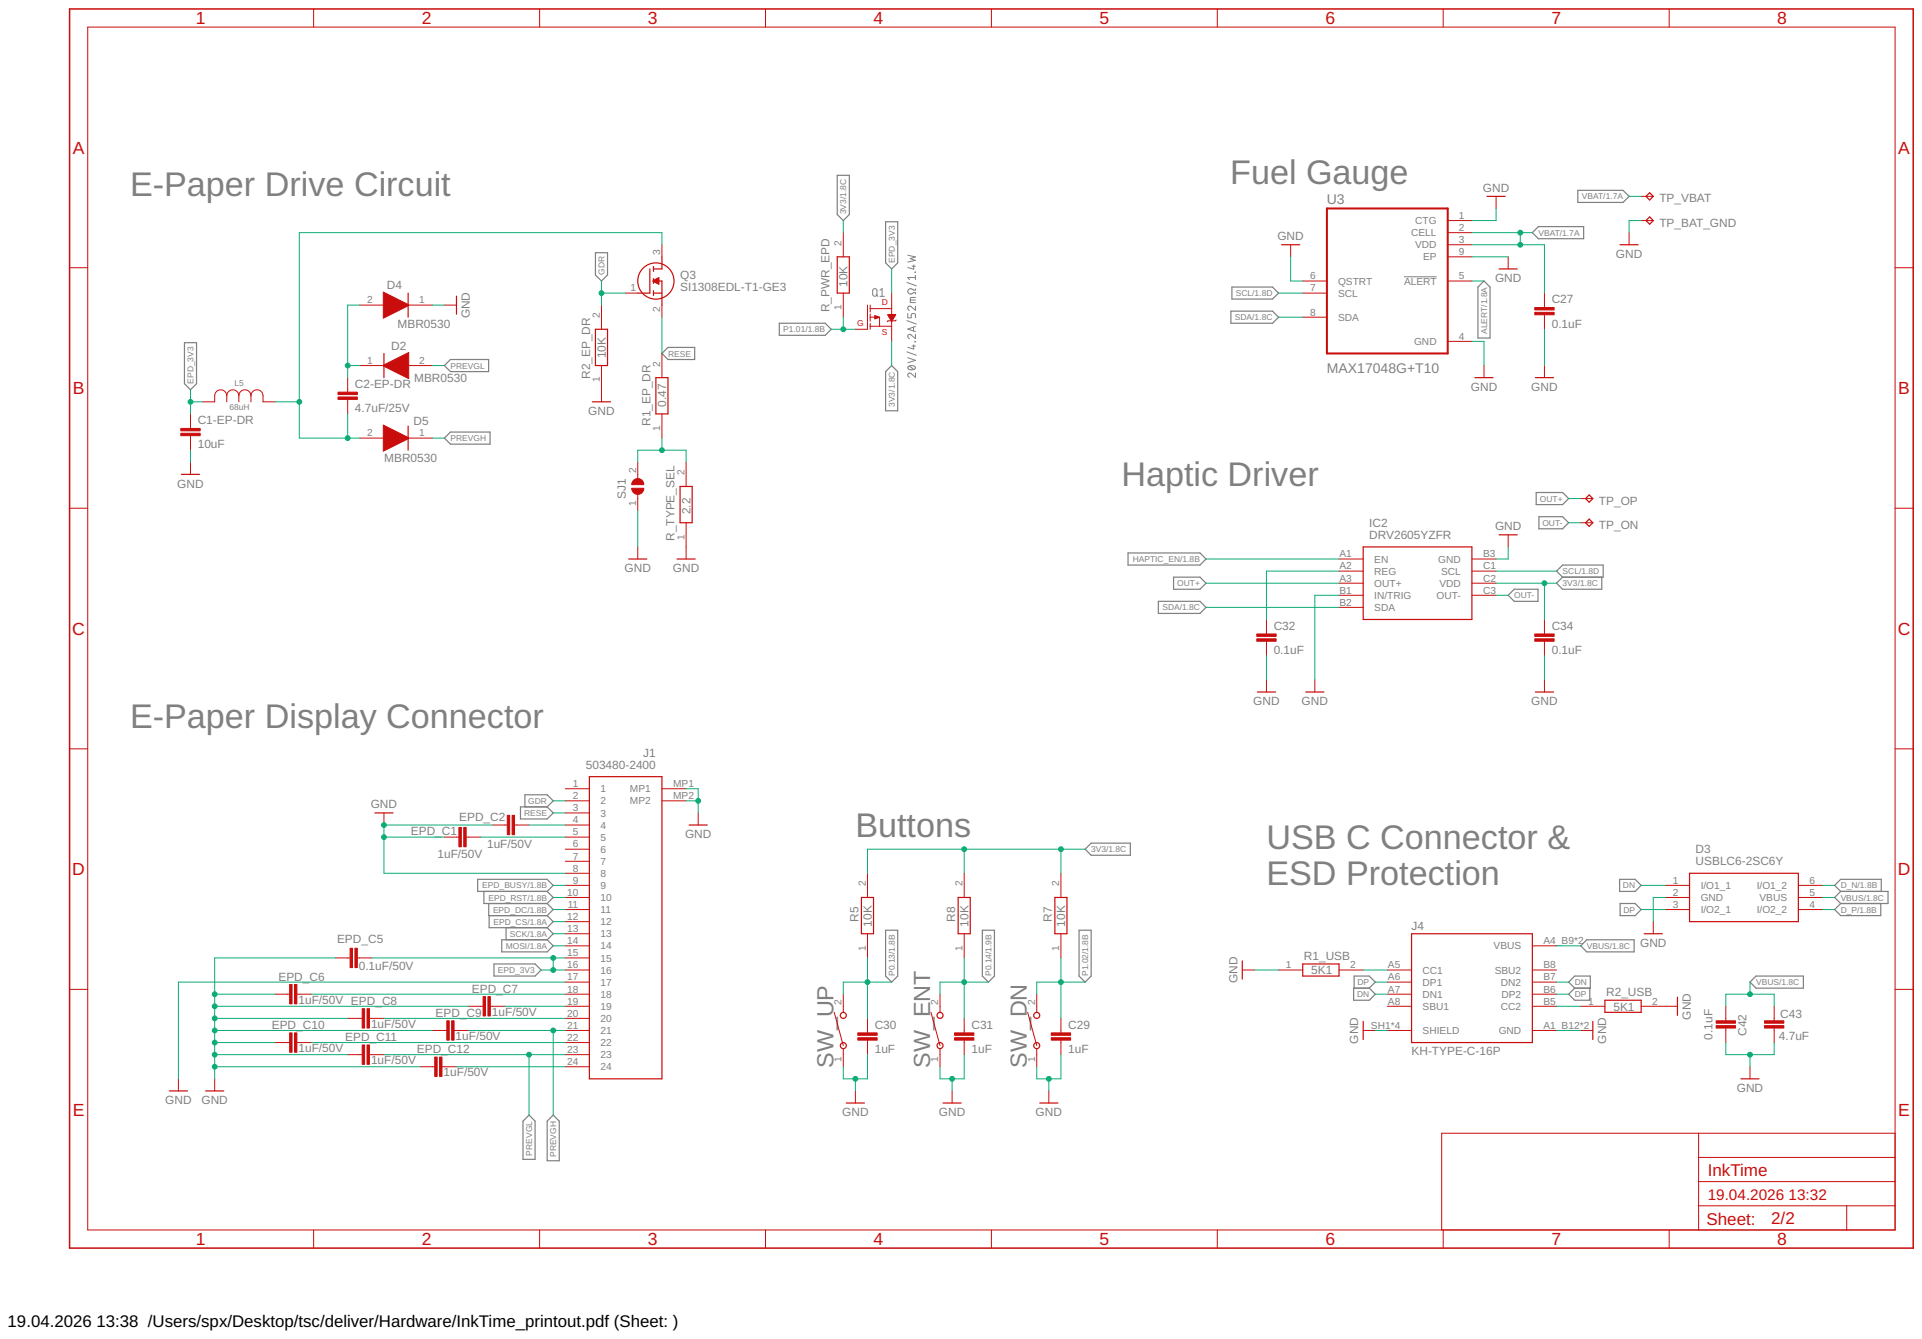
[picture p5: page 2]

EPD_C7 18
EPD_C9 | 1uF/50V 20

1uF/50V EPD_C8 | 19
EPD_C10 | 1uF/50V | 21
1uF/50V | EPD_C12 | 23

EPD_C11 | 1uF/50V | 22
1uF/50V | | | 24

19.04.2026 13:38 /Users/spx/Desktop/tsc/deliver/Hardware/InkTime_printout.pdf (Sheet: )

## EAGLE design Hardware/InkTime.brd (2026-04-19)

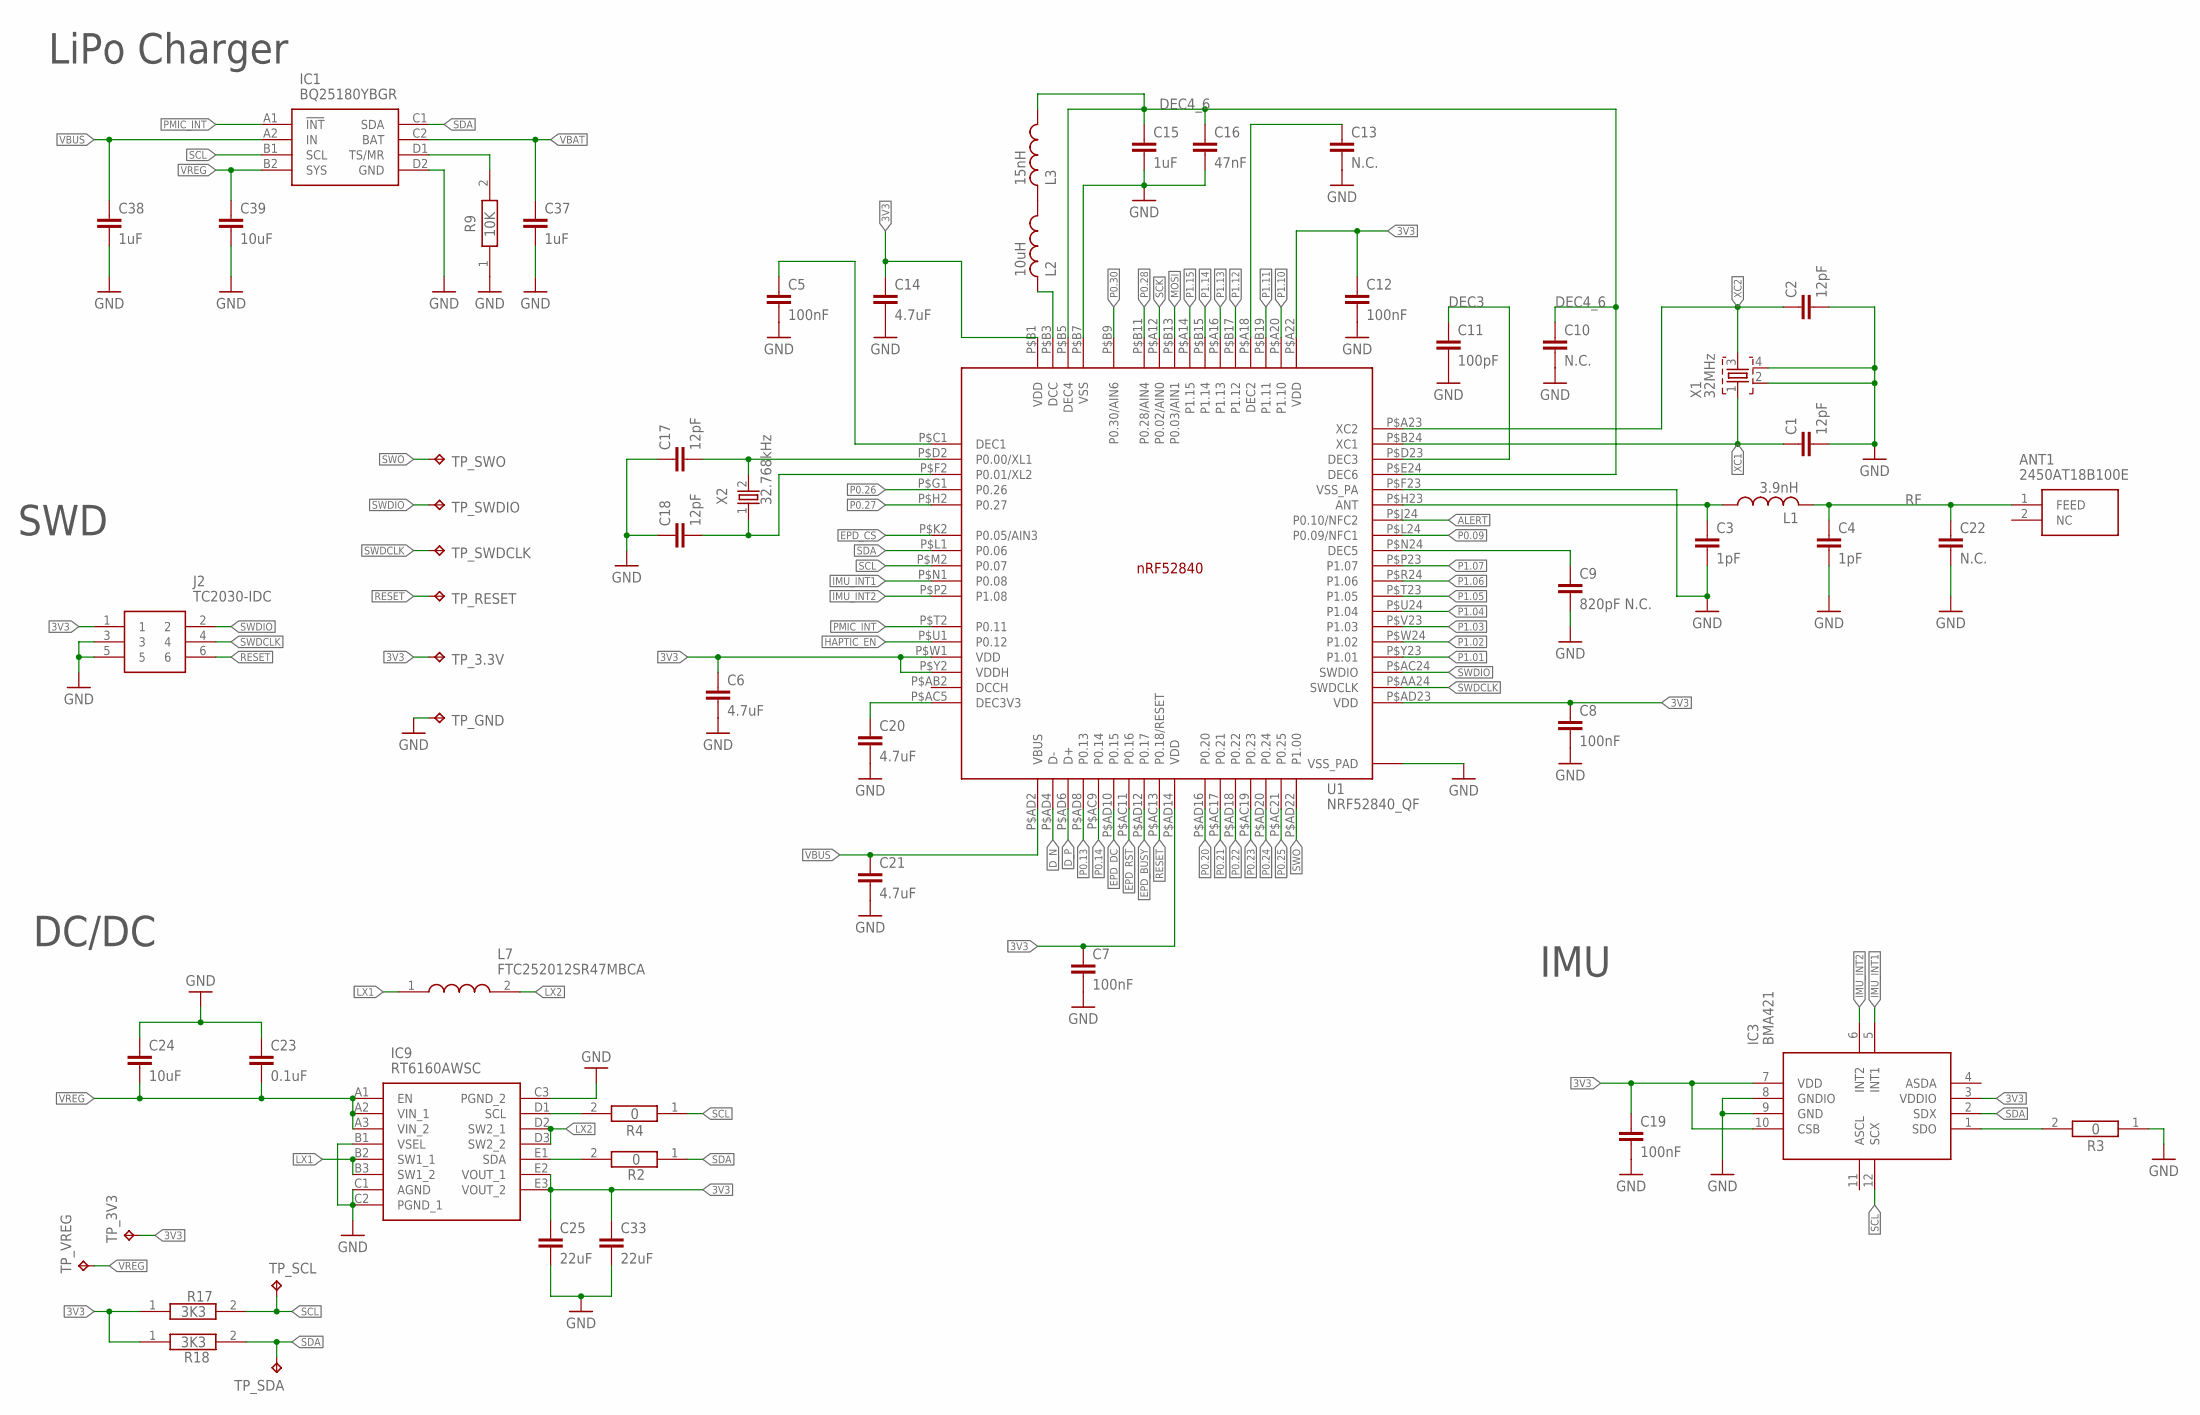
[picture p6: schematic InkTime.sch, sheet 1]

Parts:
ANT1: 2450AT18B100E; 2450AT18B100E_ANTC3216X140N
C1, C2, C17, C18: 12pF; NORDIC_NRF_3_RESC0201_N
C3, C4: 1pF; NORDIC_NRF_3_RESC0201_N
C5, C7, C8, C12, C19: 100nF; NORDIC_NRF_3_RESC0201_N
C6, C14, C20, C21: 4.7uF; NORDIC_NRF_3_RESC0402_N
C9: 820pF N.C.; NORDIC_NRF_3_RESC0201_N
C10, C13, C22: N.C.; NORDIC_NRF_3_RESC0201_N
C11: 100pF; NORDIC_NRF_3_RESC0201_N
C15, C37, C38: 1uF; NORDIC_NRF_3_RESC0402_N
C16: 47nF; NORDIC_NRF_3_RESC0201_N
C23: 0.1uF; NORDIC_NRF_3_RESC0201_N
C24, C39: 10uF; NORDIC_NRF_3_RESC0402_N
C25, C33: 22uF; NORDIC_NRF_3_RESC0402_N
IC1: BQ25180YBGR; BQ25180YBGR_BGA8C40P2X4_100X155X50
IC3: BMA421; BMA423_BMA423
IC9: RT6160AWSC; RT6160AWSC_BGA15C40P3X5_140X230X60
J2: TC2030-IDC; TC2030-IDC_TC2030IDC
L1: 3.9nH; NORDIC_NRF_2_RESC0402_N
L2: 10uH; NORDIC_NRF_2_RESC0603_N
L3: 15nH; NORDIC_NRF_2_RESC0402_N
L7: FTC252012SR47MBCA; MLP2016SR47MT0S1_INDC2016X100N
R2, R3, R4: 0; CPF0201D7K68C1_0201
R9: 10K; CPF0201D7K68C1_0201
R17, R18: 3K3; CPF0201D7K68C1_0201
TP_3.3V, TP_3V3: HECTOR_WATCH_1_TPTP20R; HECTOR_WATCH_1_TP20R
TP_GND: HECTOR_WATCH_1_TPTP20R; HECTOR_WATCH_1_TP20R
TP_RESET: HECTOR_WATCH_1_TPTP20R; HECTOR_WATCH_1_TP20R
TP_SCL: HECTOR_WATCH_1_TPTP20R; HECTOR_WATCH_1_TP20R
TP_SDA: HECTOR_WATCH_1_TPTP20R; HECTOR_WATCH_1_TP20R
TP_SWDCLK: HECTOR_WATCH_1_TPTP20R; HECTOR_WATCH_1_TP20R
TP_SWDIO: HECTOR_WATCH_1_TPTP20R; HECTOR_WATCH_1_TP20R
TP_SWO: HECTOR_WATCH_1_TPTP20R; HECTOR_WATCH_1_TP20R
TP_VREG: HECTOR_WATCH_1_TPTP20R; HECTOR_WATCH_1_TP20R
U1: NRF52840_QF; NORDIC_NRF_4_AQFN50P700X700X85_HS-74N_PINCLEAN2
X1: 32MHz; NORDIC_NRF_BT-XTAL_2016_N
X2: 32.768kHz; NORDIC_NRF_1_XTAL_3215_N

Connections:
3V3: C6.1, C7.1, C8.1, C12.1, C14.1, C19.1, C25.1, C33.1, IC3.3 (VDDIO), IC3.7 (VDD), IC3.10 (CSB), IC9.E2 (VOUT_1), IC9.E3 (VOUT_2), J2.1, R17.1, R18.1, TP_3.3V.TP, TP_3V3.TP, U1.P$A22 (VDD), U1.P$AD14 (VDD), U1.P$AD23 (VDD), U1.P$B1 (VDD), U1.P$W1 (VDD), U1.P$Y2 (VDDH); also elsewhere on the board
ALERT: U1.P$J24 (P0.10/NFC2); also elsewhere on the board
DEC3: C11.1, U1.P$D23 (DEC3)
DEC4_6: C10.1, C15.1, C16.1, L3.1, U1.P$B5 (DEC4), U1.P$E24 (DEC6)
D_N: U1.P$AD4 (D-); also elsewhere on the board
D_P: U1.P$AD6 (D+); also elsewhere on the board
EPD_BUSY: U1.P$AD12 (P0.17); also elsewhere on the board
EPD_CS: U1.P$K2 (P0.05/AIN3); also elsewhere on the board
EPD_DC: U1.P$AD10 (P0.15); also elsewhere on the board
EPD_RST: U1.P$AC11 (P0.16); also elsewhere on the board
GND: C1.2, C2.2, C3.2, C4.2, C5.2, C6.2, C7.2, C8.2, C9.2, C10.2, C11.2, C12.2, C13.2, C14.2, C15.2, C16.2, C17.1, C18.1, C19.2, C20.2, C21.2, C22.2, C23.1, C24.1, C25.2, C33.2, C37.2, C38.2, C39.2, IC1.D2 (GND), IC3.8 (GNDIO), IC3.9 (GND), IC9.B1 (VSEL), IC9.C1 (AGND), IC9.C2 (PGND_1), IC9.C3 (PGND_2), J2.3, J2.5, R3.1, R9.1, TP_GND.TP, U1.P$74 (VSS_PAD), U1.P$75 (VSS_PAD), U1.P$76 (VSS_PAD), U1.P$77 (VSS_PAD), U1.P$78 (VSS_PAD), U1.P$79 (VSS_PAD), U1.P$80 (VSS_PAD), U1.P$81 (VSS_PAD), U1.P$82 (VSS_PAD), U1.P$83 (VSS_PAD), U1.P$84 (VSS_PAD), U1.P$85 (VSS_PAD), U1.P$86 (VSS_PAD), U1.P$87 (VSS_PAD), U1.P$88 (VSS_PAD), U1.P$89 (VSS_PAD), U1.P$90 (VSS_PAD), U1.P$B7 (VSS), U1.P$F23 (VSS_PA), X1.2, X1.4; also elsewhere on the board
HAPTIC_EN: U1.P$U1 (P0.12); also elsewhere on the board
IMU_INT1: IC3.5 (INT1), U1.P$N1 (P0.08)
IMU_INT2: IC3.6 (INT2), U1.P$P2 (P1.08)
LX1: IC9.B2 (SW1_1), IC9.B3 (SW1_2), L7.1
LX2: IC9.D2 (SW2_1), IC9.D3 (SW2_2), L7.2
MOSI: U1.P$B13 (P0.03/AIN1); also elsewhere on the board
unnamed: L2.1, L3.2
unnamed: L2.2, U1.P$B3 (DCC)
unnamed: IC1.D1 (TS/MR), R9.2
unnamed: C3.1, L1.1, U1.P$H23 (ANT)
unnamed: C9.1, U1.P$N24 (DEC5)
unnamed: C17.2, U1.P$D2 (P0.00/XL1), X2.2
unnamed: C5.1, U1.P$C1 (DEC1)
unnamed: IC9.E1 (SDA), R2.2
unnamed: C20.1, U1.P$AC5 (DEC3V3)
unnamed: IC9.D1 (SCL), R4.2
unnamed: IC3.1 (SDO), R3.2
unnamed: C18.2, U1.P$F2 (P0.01/XL2), X2.1
unnamed: C13.1, U1.P$A18 (DEC2)
P0.09: U1.P$L24 (P0.09/NFC1)
P0.13: U1.P$AD8 (P0.13); also elsewhere on the board
P0.14: U1.P$AC9 (P0.14); also elsewhere on the board
P0.20: U1.P$AD16 (P0.20)
P0.21: U1.P$AC17 (P0.21)
P0.22: U1.P$AD18 (P0.22)
P0.23: U1.P$AC19 (P0.23)
P0.24: U1.P$AD20 (P0.24)
P0.25: U1.P$AC21 (P0.25)
P0.26: U1.P$G1 (P0.26)
P0.27: U1.P$H2 (P0.27)
P0.28: U1.P$B11 (P0.28/AIN4)
P0.30: U1.P$B9 (P0.30/AIN6)
P1.01: U1.P$Y23 (P1.01); also elsewhere on the board
P1.02: U1.P$W24 (P1.02); also elsewhere on the board
P1.03: U1.P$V23 (P1.03)
P1.04: U1.P$U24 (P1.04)
P1.05: U1.P$T23 (P1.05)
P1.06: U1.P$R24 (P1.06)
P1.07: U1.P$P23 (P1.07)
P1.10: U1.P$A20 (P1.10)
P1.11: U1.P$B19 (P1.11)
P1.12: U1.P$B17 (P1.12)
P1.13: U1.P$A16 (P1.13)
P1.14: U1.P$B15 (P1.14)
P1.15: U1.P$A14 (P1.15)
PMIC_INT: IC1.A1 (!INT), U1.P$T2 (P0.11)
RESET: J2.6, TP_RESET.TP, U1.P$AC13 (P0.18/RESET)
RF: ANT1.1 (FEED), C4.1, C22.1, L1.2
SCK: U1.P$A12 (P0.02/AIN0); also elsewhere on the board
SCL: IC1.B1 (SCL), IC3.12 (SCX), R4.1, R17.2, TP_SCL.TP, U1.P$M2 (P0.07); also elsewhere on the board
SDA: IC1.C1 (SDA), IC3.2 (SDX), R2.1, R18.2, TP_SDA.TP, U1.P$L1 (P0.06); also elsewhere on the board
SWDCLK: J2.4, TP_SWDCLK.TP, U1.P$AA24 (SWDCLK)
SWDIO: J2.2, TP_SWDIO.TP, U1.P$AC24 (SWDIO)
SWO: TP_SWO.TP, U1.P$AD22 (P1.00)
VBAT: C37.1, IC1.C2 (BAT); also elsewhere on the board
VBUS: C21.1, C38.1, IC1.A2 (IN), U1.P$AD2 (VBUS); also elsewhere on the board
VREG: C23.2, C24.2, C39.1, IC1.B2 (SYS), IC9.A1 (EN), IC9.A2 (VIN_1), IC9.A3 (VIN_2), TP_VREG.TP
XC1: C1.1, U1.P$B24 (XC1), X1.1
XC2: C2.1, U1.P$A23 (XC2), X1.3

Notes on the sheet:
LiPo Charger
DC/DC
IMU
SWD

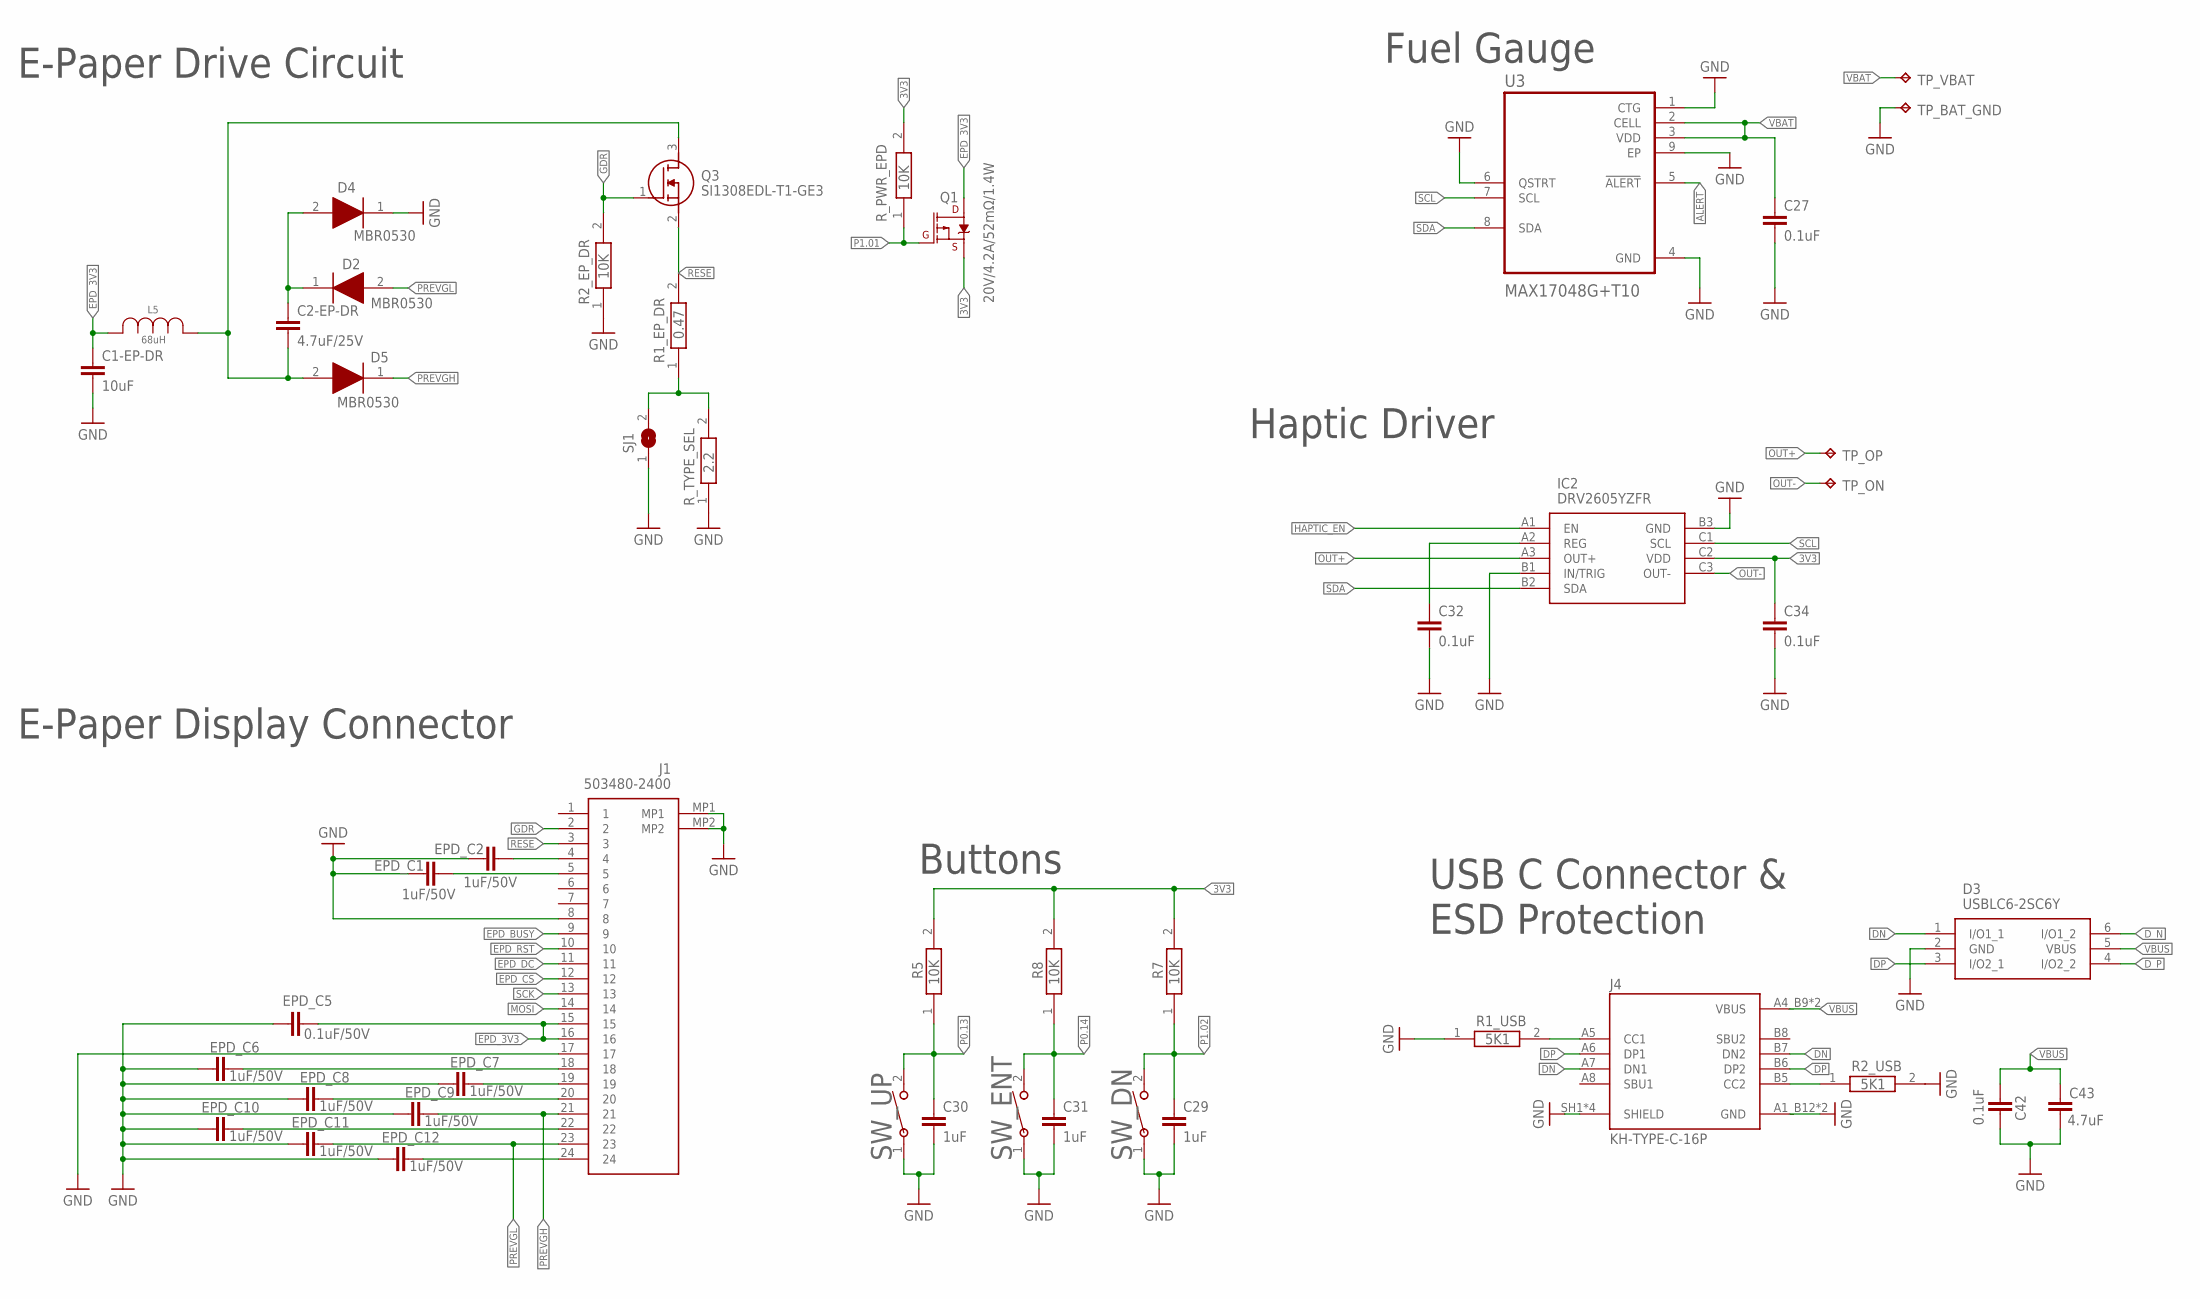
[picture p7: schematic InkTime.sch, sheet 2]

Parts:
C1-EP-DR: 10uF; NORDIC_NRF_3_RESC0402_N
C2-EP-DR: 4.7uF/25V; NORDIC_NRF_3_RESC0402_N
C27, C32, C34, C42: 0.1uF; NORDIC_NRF_3_RESC0201_N
C29, C30, C31: 1uF; NORDIC_NRF_3_RESC0402_N
C43: 4.7uF; NORDIC_NRF_3_RESC0402_N
D2, D4, D5: MBR0530; ESP32_C6_LIBRARY_5_SOD3716X135N
D3: USBLC6-2SC6Y; ESP32_C6_LIBRARY_3_SOT95P280X145-6N
EPD_C1, EPD_C2, EPD_C6, EPD_C7, EPD_C8, EPD_C9, EPD_C10, EPD_C11, EPD_C12: 1uF/50V; NORDIC_NRF_3_RESC0402_N
EPD_C5: 0.1uF/50V; NORDIC_NRF_3_RESC0402_N
IC2: DRV2605YZFR; DRV2605YZFR_BGA9C50P3X3_144X144X62
J1: 503480-2400; 503480-2400_5034802400
J4: KH-TYPE-C-16P; KH-TYPE-C-16P_KINGHELM_KH-TYPE-C-16P
L5: 68uH; ESP32_C6_LIBRARY_2_IND_4828-WE-TPC_WRE
Q1: 20V/4.2A/52mΩ/1.4W; ESP32_C6_LIBRARY_4_ESP32_C6_LIBRARY_4_ESP32_C6_LIBRARY_4_ES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
Q3: SI1308EDL-T1-GE3; ESP32_C6_LIBRARY_6_SOT65P210X110-3N
R1_EP_DR: 0.47; CPF0201D7K68C1_0201
R1_USB, R2_USB: 5K1; CPF0201D7K68C1_0201
R2_EP_DR, R5, R7, R8: 10K; CPF0201D7K68C1_0201
R_PWR_EPD: 10K; CPF0201D7K68C1_0201
R_TYPE_SEL: 2.2; CPF0201D7K68C1_0201
SJ1: ESP32_C6_LIBRARY_7_JUMPER_SJ
SW_DN: 2025-10-22_07-23-44_LIBRARY_EVP-AKE31ASW_EVP-AKE3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; 2025-10-22_07-23-44_LIBRARY_SW_EVP-AKE31A_PAN
SW_ENT: 2025-10-22_07-23-44_LIBRARY_EVP-AKE31ASW_EVP-AKE3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; 2025-10-22_07-23-44_LIBRARY_SW_EVP-AKE31A_PAN
SW_UP: 2025-10-22_07-23-44_LIBRARY_EVP-AKE31ASW_EVP-AKE3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; 2025-10-22_07-23-44_LIBRARY_SW_EVP-AKE31A_PAN
TP_BAT_GND: HECTOR_WATCH_1_TPTP20R; HECTOR_WATCH_1_TP20R
TP_ON: HECTOR_WATCH_1_TPTP20R; HECTOR_WATCH_1_TP20R
TP_OP: HECTOR_WATCH_1_TPTP20R; HECTOR_WATCH_1_TP20R
TP_VBAT: HECTOR_WATCH_1_TPTP20R; HECTOR_WATCH_1_TP20R
U3: MAX17048G+T10; ESP32_C6_LIBRARY_SON50P200X200X80-9N

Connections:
3V3: C34.1, IC2.C2 (VDD), Q1.2 (S), R5.2, R7.2, R8.2, R_PWR_EPD.2; also elsewhere on the board
ALERT: U3.5 (!ALERT); also elsewhere on the board
DN: D3.1 (I/O1_1), J4.A7 (DN1), J4.B7 (DN2)
DP: D3.3 (I/O2_1), J4.A6 (DP1), J4.B6 (DP2)
D_N: D3.6 (I/O1_2); also elsewhere on the board
D_P: D3.4 (I/O2_2); also elsewhere on the board
EPD_3V3: C1-EP-DR.1, EPD_C5.2, J1.15, J1.16, L5.2, Q1.3 (D)
EPD_BUSY: J1.9; also elsewhere on the board
EPD_CS: J1.12; also elsewhere on the board
EPD_DC: J1.11; also elsewhere on the board
EPD_RST: J1.10; also elsewhere on the board
GDR: J1.2, Q3.1 (G), R2_EP_DR.2
GND: C1-EP-DR.2, C27.2, C29.2, C30.2, C31.2, C32.2, C34.2, C42.2, C43.2, D3.2 (GND), D4.1 (K), EPD_C1.1, EPD_C2.1, EPD_C5.1, EPD_C6.1, EPD_C7.1, EPD_C8.1, EPD_C9.1, EPD_C10.1, EPD_C11.1, EPD_C12.1, IC2.B1 (IN/TRIG), IC2.B3 (GND), J1.8, J1.17, J1.MP1, J1.MP2, J4.A1_B12 (GND), J4.A12_B1 (GND), J4.SH1 (SHIELD), J4.SH2 (SHIELD), J4.SH3 (SHIELD), J4.SH4 (SHIELD), R1_USB.1, R2_EP_DR.1, R2_USB.2, R_TYPE_SEL.1, SJ1.1, SW_DN.1, SW_ENT.1, SW_UP.1, TP_BAT_GND.TP, U3.1 (CTG), U3.4 (GND), U3.6 (QSTRT), U3.9 (EP); also elsewhere on the board
HAPTIC_EN: IC2.A1 (EN); also elsewhere on the board
MOSI: J1.14; also elsewhere on the board
unnamed: J4.A5 (CC1), R1_USB.2
unnamed: EPD_C2.2, J1.4
unnamed: R1_EP_DR.1, R_TYPE_SEL.2, SJ1.2
unnamed: EPD_C1.2, J1.5
unnamed: C2-EP-DR.2, D5.2 (A), L5.1, Q3.3 (D)
unnamed: C32.1, IC2.A2 (REG)
unnamed: C2-EP-DR.1, D2.1 (K), D4.2 (A)
unnamed: J4.B5 (CC2), R2_USB.1
unnamed: EPD_C6.2, J1.18
unnamed: EPD_C7.2, J1.19
unnamed: EPD_C8.2, J1.20
unnamed: EPD_C10.2, J1.22
unnamed: EPD_C12.2, J1.24
OUT+: IC2.A3 (OUT+), TP_OP.TP
OUT-: IC2.C3 (OUT-), TP_ON.TP
P0.13: C30.1, R5.1, SW_UP.2; also elsewhere on the board
P0.14: C31.1, R8.1, SW_ENT.2; also elsewhere on the board
P1.01: Q1.1 (G), R_PWR_EPD.1; also elsewhere on the board
P1.02: C29.1, R7.1, SW_DN.2; also elsewhere on the board
PREVGH: D5.1 (K), EPD_C9.2, J1.21
PREVGL: D2.2 (A), EPD_C11.2, J1.23
RESE: J1.3, Q3.2 (S), R1_EP_DR.2
SCK: J1.13; also elsewhere on the board
SCL: IC2.C1 (SCL), U3.7 (SCL); also elsewhere on the board
SDA: IC2.B2 (SDA), U3.8 (SDA); also elsewhere on the board
VBAT: C27.1, TP_VBAT.TP, U3.2 (CELL), U3.3 (VDD); also elsewhere on the board
VBUS: C42.1, C43.1, D3.5 (VBUS), J4.A4_B9 (VBUS), J4.A9_B4 (VBUS); also elsewhere on the board

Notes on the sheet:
E-Paper Drive Circuit
E-Paper Display Connector
Fuel Gauge
Haptic Driver
Buttons
USB C Connector & ESD Protection

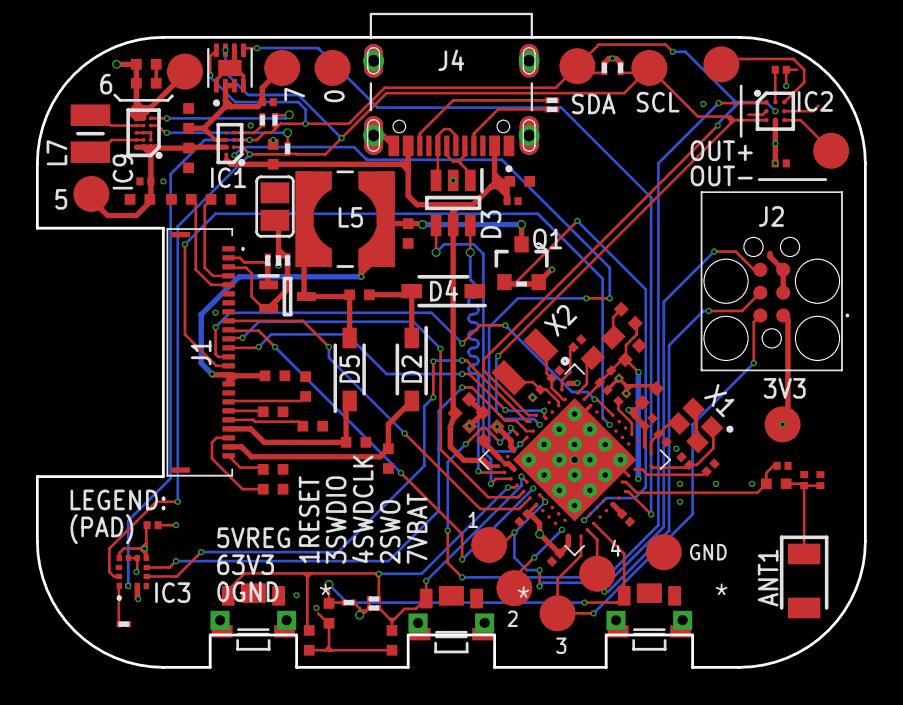
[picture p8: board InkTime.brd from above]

Board: 4 copper layers, 46.0 x 35.0 mm, 105 parts (0 on the bottom side), 70 nets.

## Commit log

2026-04-10 feat: improve case render
2026-04-13 fix: 0.47Ohm resistor identification
    [bom.xlsx]
2026-04-14 feat: finish README sections
    - add hardware functionality description
    - add BOM table + external full BOM
    - add renders
    - add design details
    [JLCPCB_BOM.xlsx]
2026-04-14 fix: BMA423 -> BMA421
    [InkTime.brd, InkTime.sch, bom.xlsx]
2026-04-19 fix: mask P0.19 from nRF package
    [InkTime.brd, InkTime.sch]
2026-04-19 feat: add printout

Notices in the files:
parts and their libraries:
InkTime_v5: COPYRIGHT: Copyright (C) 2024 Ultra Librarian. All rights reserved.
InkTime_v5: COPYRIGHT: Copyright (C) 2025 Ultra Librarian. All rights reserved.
